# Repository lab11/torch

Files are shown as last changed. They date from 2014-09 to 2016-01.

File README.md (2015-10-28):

Torch
=====

<center>
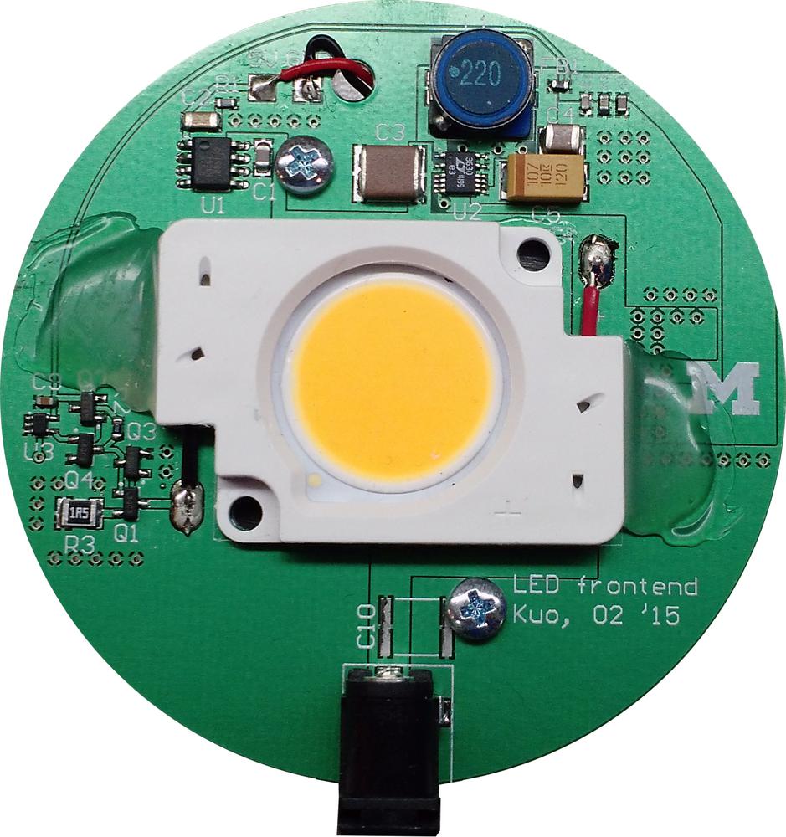
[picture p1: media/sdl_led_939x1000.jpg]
Torch

</center>

This system provides the hardware and software for a software-defined lighting platform.

Compile
-------

    git clone https://github.com/lab11/contiki
    cd contiki
    git co sdl

    cd ../torch/contiki/apps/coap
    make

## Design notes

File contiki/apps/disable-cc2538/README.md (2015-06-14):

Bare metal app that switches the antenna fully to the nRF51822.

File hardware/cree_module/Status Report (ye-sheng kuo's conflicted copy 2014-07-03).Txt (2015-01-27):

Output: NC Drill Files
Type  : NC Drill
From  : PCB Document [cree.PcbDoc]
   Generated File[cree.TXT]
   Generated File[cree.LDP]
   Generated File[cree.DRR]

Files Generated   : 3
Documents Printed : 0

Finished Output Generation At 11:31:57 AM On 5/7/2014

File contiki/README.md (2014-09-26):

Torch - Contiki
==============

This folder contains code to make Torch a
[Contiki](https://github.com/contiki-os/contiki) platform. Contiki has active
support of the CC2538 and this platform adds on drivers for the FRAM and
RTC chips.

Installation
------------

To compile apps for Torch you need this repository, the main Contiki repository,
and the toolchain.

1. Install the compilers. See
[this](https://github.com/contiki-os/contiki/tree/master/platform/cc2538dk#install-a-toolchain)
for a link to the best compiler to use for the CC2538

2. Clone the main contiki repository

        git clone https://github.com/contiki-os/contiki.git

3. Add the `/tools` directory in this folder to your path. This folder contains
a script for initializing the RTC with the current time. Something like:

        export PATH=$PATH:$HOME/git/torch/contiki/tools

4. Make sure the applications know where the main Contiki repository is.
Edit `apps/blink/Makefile` and make sure that `CONTIKI = ../../../../contiki`
actually points to where you cloned the Contiki repository.

Compiling an Application
------------------------

At this point compiling a Contiki application for torch 
should be very straightforward.

    cd apps/blink
    make

If you wanted to use a different platform (say the CC2538 evm with the SmartRF06
board):

    make TARGET=cc2538dk

Loading the Application to Torch
-------------------------------

Assuming you are using the serial bootloader (pins GND, VCC, !RESET,
BOOTLOADER_CTRL, BOOTLOADER_TX, and BOOTLOADER_RX) you can use the wonderful
[BSL script from JelmerT](https://github.com/JelmerT/cc2538-bsl) by:

    make install

Errors
------

It's possible these steps will not work. A major reason why is that the CC2538
platform in Contiki is changing rapidly and often adds in new features that
won't compile until the Torch platform is similarly updated. If this happens,
please raise an issue on this repository so that I can fix it.

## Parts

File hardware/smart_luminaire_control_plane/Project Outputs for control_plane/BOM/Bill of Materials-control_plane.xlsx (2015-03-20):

Designator | Value | Quantity | Footprint | Description | Supplier Part Number 1 | Comment
ANT1 |  | 1 | Chip Antenna | 2.4GHz Surface Mount Device (SMD) On Ground Antenna, 50 Ohms | FR05-S1-N-0102B
B1 |  | 1 | BAL-NRF01D3 | 50 ohm nominal input / conjugate match balun to nRF51822-CEAA | 497-13637-1-ND
B2 |  | 1 | 2450BM15A0002 | 2.45 GHz Balun for TI CC253X | 712-1536-1-ND
C1, C3, C5 | 4.7 uF | 3 | 0603 | Ceramic capacitor, 4.7u, 10V, 0603 package | 445-7482-1-ND
C2 | 1 uF | 1 | 0603 | Ceramic capacitor, 1 uF, 16 V, 0603 package | 445-1604-1-ND
C4 | 10000 pF | 1 | 0402 | Ceramic capacitor, 10000 pF, 16 V, 0402 package | 490-1313-1-ND
C6 | 10 uF | 1 | 0603 | Ceramic capacitor, 10 uF, 16 V, 0603 package | 445-9065-6-ND
C7, C9, C17, C25 | 1 uF | 4 | 0402 | Ceramic capacitor, 1 uF, 16V, 0402 package | 445-4978-1-ND
C8, C10, C11, C12, C13, C15, C16, C18, C19, C21, C23, C26, C27, C35, C46 | 0.1 uF | 15 | 0402 | Ceramic capacitor, 0.1u, 0402 package | 445-1265-1-ND
C14 | 220 pF | 1 | 0402 | Ceramic capacitor, 220 pF, 0402 package | 445-1254-1-ND
C20 | 0.047 uF | 1 | 0402 | Ceramic capacitor, 0.047u, 16V, 0402 package | 445-1264-1-ND
C22, C30, C36, C43 | 1000 pF | 4 | 0402 | Ceramic capacitor, 1000 pF, 0402 package | 445-6846-1-ND
C24 | 4.7 uF | 1 | 0603 - Polar Marking | Tantalum capacitor, 4.7 uF, 0603 package | 511-1496-1-ND
C28, C29 | 47 pF | 2 | 0402 | Ceramic capacitor, 47 pF, 0402 package | 709-1121-1-ND
C31, C32 | 22 pF | 2 | 0402 | Ceramic capacitor, 22 pF, 0402 package | 712-1274-1-ND
C33, C34 | 13 pF | 2 | 0402 | Ceramic capacitor, 13 pF, 50 V, 0402 package | 490-5925-1-ND
C37, C38, C40 | 100 pF | 3 | 0402 | Ceramic capacitor, 100 pF, 0402 package | 399-11246-1-ND
C39 | 2200 pF | 1 | 0402 | Ceramic capacitor, 2200 pF, 0402 package | 445-1257-1-ND
C41, C42, C44, C45 | 12 pF | 4 | 0402 | Ceramic capacitor, 12 pF, 0402 package | 712-1256-1-ND
D1, D4 |  | 2 | 0402 - DIODE | LED, Green, 0402 | 511-1592-1-ND
D2 |  | 1 | 0402 - DIODE | LED, Orange, 0402 | 511-1590-1-ND
D3 |  | 1 | 0402 - DIODE | LED, Red, 0402 | 511-1593-1-ND
FB1 |  | 1 | 0402 | Ferrite Bead, 150 mA, 0402 package | 587-1835-1-ND
J1 |  | 1 | Micro USB-B | CONN USB MICRO B RECPT SMT R/A | 609-4616-6-ND
P1, P3 |  | 2 | SSM-104-F-DV | Samtec 2x4 100 mil female connector | SSM-104-F-DV | Samtec
P2, P4 |  | 2 | SAM_CLP_2_4 | Samtec CLP 2x4 0.05" Female Header | CLP-104-02-G-D | Samtec
P6 |  | 1 | CAS-220A | DPDT dip switch | CAS220JCT-ND
R1, R12 | 205 | 2 | 0402 | Chip resistor, 205, 0402 package | 541-205LCT-ND
R2, R3, R4 | 0 | 3 | 0402 | Chip resistor, 0, 0402 package | 541-0.0YBCT-ND
R15, R24 | 0 | 2 | 0402 | Chip resistor, 0, 0402 package | 541-0.0YBCT-ND | DNI
R5, R6 | 33 | 2 | 0402 | Chip resistor, 33, 0402 package | 541-33.0LCT-ND | DNI
R7, R25, R26 | 100K | 3 | 0402 | Chip resistor, 100K, 0402 package | 541-100KLCT-ND | DNI
R8 | 2.2K | 1 | 0402 | Chip resistor, 2.2K, 0402 package | 541-2.20KLCT-ND
R9 | 56K | 1 | 0402 | Chip resistor, 56K, 0402 package | P56KDECT-ND
R10 | 270 | 1 | 0402 | Chip resistor, 270, 0402 package | 541-270LCT-ND
R11 | 374 | 1 | 0402 | Chip resistor, 374, 0402 package | 541-374LCT-ND
R13, R14, R16, R17, R18, R19, R20, R21, R22, R23 | 100 | 10 | 0402 | Chip resistor, 100, 0402 package | 541-100LCT-ND
R27 | 10K | 1 | 0402 | Chip resistor, 10K, 0402 package | 541-10.0KLDKR-ND
U1 |  | 1 | DFN-10 | Dual 2.6A, 2.5V to 5.5V, Ideal Diodes in 3mm × 3mm DFN | LTC4413EDD#TRPBFCT-ND
U2 |  | 1 | SON-6 | 500mA, Low Quiescent Current, Ultra-Low Noise, High PSRR Low-Dropout Linear Regulator | 296-24289-1-ND
U3 |  | 1 | QFN56 | A Powerful System-On-Chip for 2.4-GHz IEEE 802.15.4, 6LoWPAN and ZigBee Applications | 296-35797-1-ND
U4 |  | 1 | QFN-48 | Multiprotocol Bluetooth® low energy/2.4 GHz RF System on Chip | 1490-1032-1-ND
U5 |  | 1 | QFN-32 | FT232R USB UART | 768-1008-1-ND
U6 |  | 1 | WSON | 64 Mbit SPI Serial Dual I/O Flash | SST25VF064C-80-4I-Q2AE-CT-ND
U7 |  | 1 | minimold-6 | GaAs Integrated Circuit for L, S-Band SPDT Switch | UPG2214TB-E4-ACT-ND
U8 |  | 1 | SC-70-5 (DCK) | LOW POWER, 1.8/2.5/3.3-V INPUT, 3.3-V CMOS OUTPUT, SINGLE SCHMITT-TRIGGER INVERTER GATE | 296-27392-1-ND
Y1 |  | 1 | ABS05 | 32768 Hz SMD Low profile crystal | 535-11899-1-ND
Y2 |  | 1 | ECX-31B | SMD TUNING FORK CRYSTAL | XC1950CT-ND
Y3 |  | 1 | CX2520 | Crystal oscillator | 1253-1121-1-ND
Y4 |  | 1 | FA-128 | MHz Range Crystal Unit | SER3800CT-ND
Y5 |  | 1 | RV-3049-C3 | Real Time Clock Module with SPI-Bus

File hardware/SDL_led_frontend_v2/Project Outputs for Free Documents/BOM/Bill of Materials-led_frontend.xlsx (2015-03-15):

Designator | Value | Quantity | Footprint | Description | Supplier Part Number 1
C1 | 1 uF | 1 | 0805 | Ceramic capacitor, 1 uF, 100 V, 0805 package | 445-5205-1-ND
C2 | 22 uF | 1 | 1206 | Ceramic capacitor, 22 uF, 1206 package | 1276-2728-1-ND
C3, C10 | 4.7 uF | 2 | 2220 | Ceramic capacitor, 4.7u, 2220 package | 445-1450-1-ND
C4 | 100 uF | 1 | 1210 | Ceramic capacitor, 100u, 1210 package | 1276-3364-1-ND
C5 | 100 uF | 1 | 2917 | Tantalum capacitor, 100u, 2917 package | 399-3769-1-ND
C6, C9 | 0.1 uF | 2 | 0603 | Ceramic capacitor, 0.1 uF, 0603 package | 445-1316-1-ND
C7 | 1 uF | 1 | 0603 | Ceramic capacitor, 1 uF, 16 V, 0603 package | 445-1604-1-ND
C8 | 10 uF | 1 | 0603 | Ceramic capacitor, 10 uF, 16 V, 0603 package | 445-9065-6-ND
FB1 |  | 1 | 0603 | Ferrite Bead, 500 mA, 0603 package | 490-1011-1-ND
J1 |  | 1 | molex | LED Array Holders for CREE* XLamp† Arrays | WM10352-ND
J2 |  | 1 | PJ-102AH | CONN PWR JACK 2.1X5.5MM HIGH CUR | CP-102AH-ND
L1 | 22 uH | 1 | SLF10145 | Inductor, 22 uH, TDK SLF10145 | 445-1981-1-ND
P1, P2 |  | 2 | HW-04-20-F-D-900-SM | Samtec 2x4 100 mil connector
P3 |  | 1 | 2x2 header SMD | 2x2 100 mil header SMD | 609-4463-6-ND
Q1, Q3, Q4 |  | 3 | SOT23-3 | N-Channel 60-V (D-S) MOSFET | SI2308BDS-T1-E3CT-ND
Q2 |  | 1 | SOT23-3 | P-Channel 60-V (D-S) MOSFET | SI2309CDS-T1-E3CT-ND
R1 | 1 | 1 | 0603 | Chip resistor, 1, 0603 package | 541-1.00HHCT-ND
R2 | 47 | 1 | 0603 | Chip resistor, 47, 0603 package | 541-47.0HCT-ND
R3 | 1.5 | 1 | 1210 | Chip resistor, 1.5, 1210 package | P1.5VTR-ND
U1 |  | 1 | SOIC-8 | Ultra-Low Quiescent Current LDO Voltage Regulator | LM2936HVMAX-5.0/NOPBCT-ND
U2 |  | 1 | MSE16(12) | High Efficiency, 65V 500mA synchronous Step-Down Converter | LTC3630EMSE#PBF-ND
U3 |  | 1 | SC-70-5 (DCK) | LOW POWER, 1.8/2.5/3.3-V INPUT, 3.3-V CMOS OUTPUT, SINGLE SCHMITT-TRIGGER INVERTER GATE | 296-27392-1-ND

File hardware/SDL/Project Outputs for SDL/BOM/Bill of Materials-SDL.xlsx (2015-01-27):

Designator | Value | Quantity | Footprint | Description | Supplier 1 | Supplier Part Number 1 | Comments
ANT1 |  | 1 | Chip Antenna | 2.4GHz Surface Mount Device (SMD) On Ground Antenna, 50 Ohms | RichardsonRFPD | FR05-S1-N-0102B
B1 |  | 1 | 2450BM14A0002 | 2.45 GHz Balun for nRF8001 | Digi-Key | 712-1574-1-ND
B2 |  | 1 | 2450BM15A0002 | 2.45 GHz Balun for TI CC253X | Digi-Key | 712-1536-1-ND
C1, C3, C5, C6, C8, C9, C10, C16, C19, C22, C23, C30, C34, C46, C47 | 0.1 uF | 15 | 0402 | Ceramic capacitor, 0.1u, 0402 package | Digi-Key | 445-1265-1-ND
C2, C4, C11, C17, C21, C33 | 1 uF | 6 | 0402 | Ceramic capacitor, 1 uF, 0402 package | Digi-Key | 445-5000-1-ND
C7 | 220 pF | 1 | 0402 | Ceramic capacitor, 220 pF, 0402 package | Digi-Key | 445-1254-1-ND
C12, C28, C39, C43 | 1000 pF | 4 | 0402 | Ceramic capacitor, 1000 pF, 0402 package | Digi-Key | 445-6846-1-ND
C36 | 1000 pF | 1 | 0402 | Ceramic capacitor, 1000 pF, 0402 package | Digi-Key | 445-6846-1-ND | No load
C13 | 4.7 uF | 1 | 2220 | Ceramic capacitor, 4.7u, 2220 package | Digi-Key | 445-1450-1-ND
C14 | 100 uF | 1 | 1210 | Ceramic capacitor, 100u, 1210 package | Digi-Key | 1276-3364-1-ND
C15 | 100 uF | 1 | 2917 | Tantalum capacitor, 100u, 2917 package | Digi-Key | 399-3769-1-ND
C18, C32 | 10 uF | 2 | 0603 | Ceramic capacitor, 10 uF, 0603 package | Digi-Key | 445-4112-1-ND
C20 | 4.7 uF | 1 | 0603 - Polar Marking | Tantalum capacitor, 4.7 uF, 0603 package | Digi-Key | 511-1496-1-ND
C24, C25 | 47 pF | 2 | 0402 | Ceramic capacitor, 47 pF, 0402 package | Digi-Key | 709-1121-1-ND
C26, C27 | 22 pF | 2 | 0402 | Ceramic capacitor, 22 pF, 0402 package | Digi-Key | 712-1274-1-ND
C29 | 1 uF | 1 | 0603 | Ceramic capacitor, 1 uF, 0603 package | Digi-Key | 445-1321-1-ND
C31 | 0.033 uF | 1 | 0402 | Ceramic capacitor, 0.033 uF, 0402 package | Digi-Key | 445-7334-1-ND
C35 | 2200 pF | 1 | 0402 | Ceramic capacitor, 2200 pF, 0402 package | Digi-Key | 445-1257-1-ND
C37, C38, C44, C45 | 12 pF | 4 | 0402 | Ceramic capacitor, 12 pF, 0402 package | Digi-Key | 712-1256-1-ND
C40, C41, C42 | 100 pF | 3 | 0402 | Ceramic capacitor, 100 pF, 0402 package | Digi-Key | 399-11246-1-ND
D1, D3 |  | 2 | 0402 - DIODE | LED, Green, 0402 | Digi-Key | 511-1592-1-ND
D2 |  | 1 | 0402 - DIODE | LED, Red, 0402 | Digi-Key | 511-1593-1-ND
FB1, FB2 |  | 2 | 0402 | Ferrite Bead, 150 mA, 0402 package | Digi-Key | 587-1835-1-ND
J1 |  | 1 | Micro USB-B | CONN USB MICRO B RECPT SMT R/A | Digi-Key | 609-4616-6-ND
J2, J3, J4, J5 |  | 4 | SFM-105-02-L-S | Samtec connector, 1.27 mm, single row, 5 pos SMD | Samtec
L1 | 22 uH | 1 | SLF10145 | Inductor, 22 uH, TDK SLF10145 | Digi-Key | 445-1981-1-ND
L2 | 15 nH | 1 | 0402 | Chip inductor, 15 nH, 0402 package | Digi-Key | 712-1408-1-ND
L3 | 10 uH | 1 | 0603 | Chip inductor, 10 uH, 0603 package | Digi-Key | 445-3608-1-ND
P1 |  | 1 | 1x3 header | 100 mils standard header | Digi-Key | 3M9448-ND
P2 |  | 1 | 2x2 header SMD | 2x2 100 mil header SMD | Digi-Key | 609-4463-6-ND
R1, R21, R23, R24 | 100K | 4 | 0402 | Chip resistor, 100K, 0402 package | Digi-Key | 541-100KLCT-ND | No load
R2 | 2.2K | 1 | 0402 | Chip resistor, 2.2K, 0402 package | Digi-Key | 541-2.20KLCT-ND
R20 | 2.2K | 1 | 0402 | Chip resistor, 2.2K, 0402 package | Digi-Key | 541-2.20KLCT-ND | No load
R3 | 56K | 1 | 0402 | Chip resistor, 56K, 0402 package | Digi-Key | P56KDECT-ND
R10 | 750 | 1 | 0402 | Chip resistor, 750, 0402 package | Digi-Key | 541-750LCT-ND
R4, R11 | 619 | 2 | 0402 | Chip resistor, 750, 0402 package | Digi-Key | 541-619LCT-ND
R5, R6, R7, R14 | 0 | 3 | 0402 | Chip resistor, 0, 0402 package | Digi-Key | 541-0.0YBCT-ND
R14 | 0 | 1 | 0402 | Chip resistor, 0, 0402 package | Digi-Key | 541-0.0YBCT-ND | No load
R8, R9 | 33 | 2 | 0402 | Chip resistor, 33, 0402 package | Digi-Key | 541-33.0LCT-ND | No load
R12, R13, R15, R16, R17, R18, R19 | 10K | 7 | 0402 | Chip resistor, 10K, 0402 package | Digi-Key | 541-10.0KLDKR-ND
R22 | 22K | 1 | 0402 | Chip resistor, 22K, 0402 package | Digi-Key | 541-22.0KLCT-ND
SW1 |  | 1 | CHS-06TA | SLIDE SWITCHES | Digi-Key | 563-1009-1-ND
U1 |  | 1 | QFN56 | A Powerful System-On-Chip for 2.4-GHz IEEE 802.15.4, 6LoWPAN and ZigBee Applications | Digi-Key | 296-35797-1-ND
U2 |  | 1 | MSE16(12) | High Efficiency, 65V 500mA synchronous Step-Down Converter | Digi-Key | LTC3630EMSE#PBF-ND
U3 |  | 1 | QFN-32 | FT232R USB UART | Digi-Key | 768-1008-1-ND
U4 |  | 1 | QFN32 | Single-chip Bluetooth low energy solution | Digi-Key | 1490-1026-ND
U5 |  | 1 | SC-70-5 (DCK) | LOW POWER, 1.8/2.5/3.3-V INPUT, 3.3-V CMOS OUTPUT, SINGLE SCHMITT-TRIGGER INVERTER GATE | Digi-Key | 296-27392-1-ND
U6 |  | 1 | WSON | 64 Mbit SPI Serial Dual I/O Flash | Digi-Key | SST25VF064C-80-4I-Q2AE-CT-ND
U7 |  | 1 | minimold-6 | GaAs Integrated Circuit for L, S-Band SPDT Switch | Digi-Key | UPG2214TB-E4-ACT-ND
Y1 |  | 1 | ABS05 | 32768 Hz SMD Low profile crystal | Digi-Key | 535-11899-1-ND
Y2 |  | 1 | TSX-3225 | MHz Range Crystal Unit | Digi-Key | SER3628CT-ND
Y3 |  | 1 | FA-128 | MHz Range Crystal Unit | Digi-Key | SER3800CT-ND | Non Stock
Y4 |  | 1 | RV4162 | Real Time Clock Module with I2C Bus | Newark | 09X0517

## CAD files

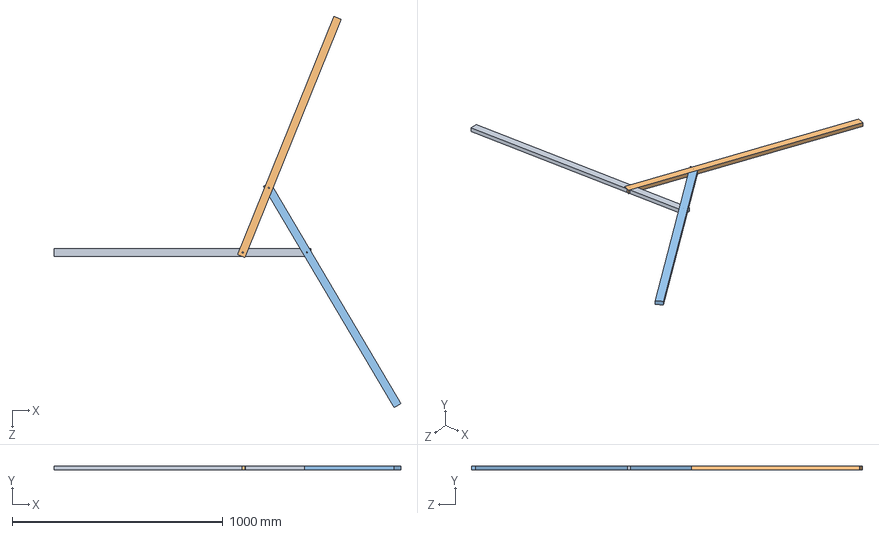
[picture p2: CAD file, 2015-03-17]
chandelier/frame.SLDASM
1646.4 x 19.1 x 1856.4 mm
frame_12
frame_13
frame_14

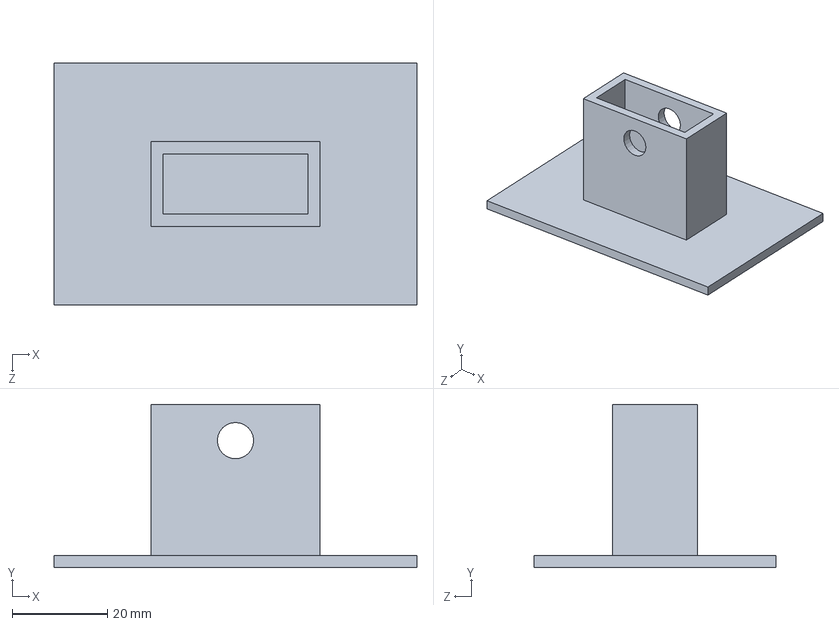
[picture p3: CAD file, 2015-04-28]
chandelier/wall_mount.SLDPRT
76.2 x 34.3 x 50.8 mm

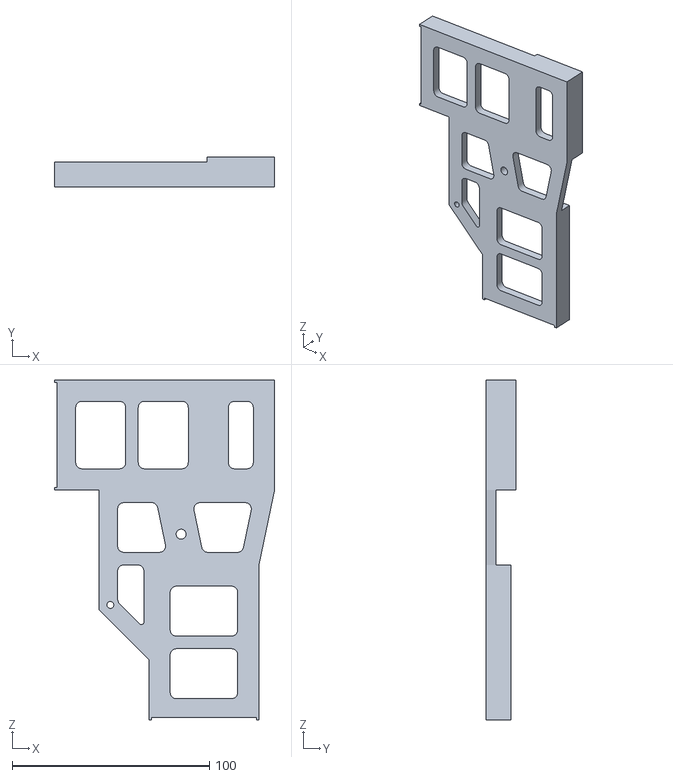
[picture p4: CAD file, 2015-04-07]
hardware/calibration/Laser_Holder.stl
111.8 x 15.2 x 172.6

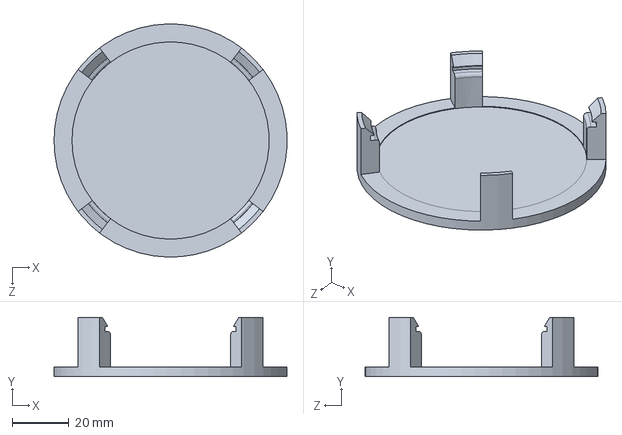
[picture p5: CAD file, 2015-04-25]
mount/torch-holder.SLDPRT
82.2 x 20.9 x 82.3 mm

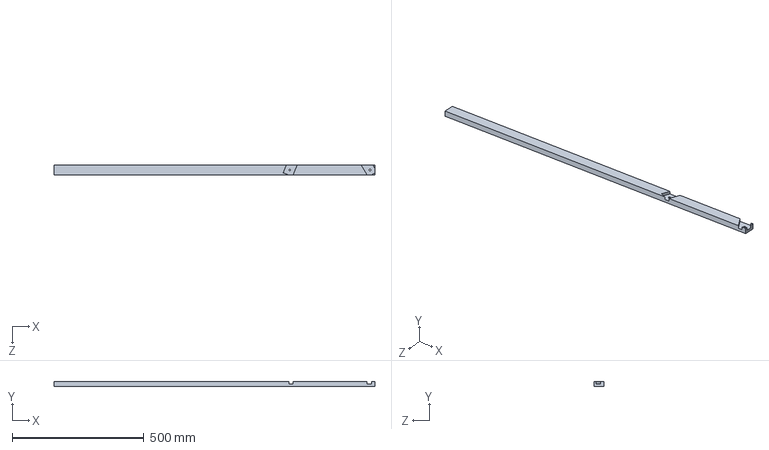
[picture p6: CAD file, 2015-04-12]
chandelier/frame_12.SLDPRT
1219.2 x 19.1 x 38.1 mm

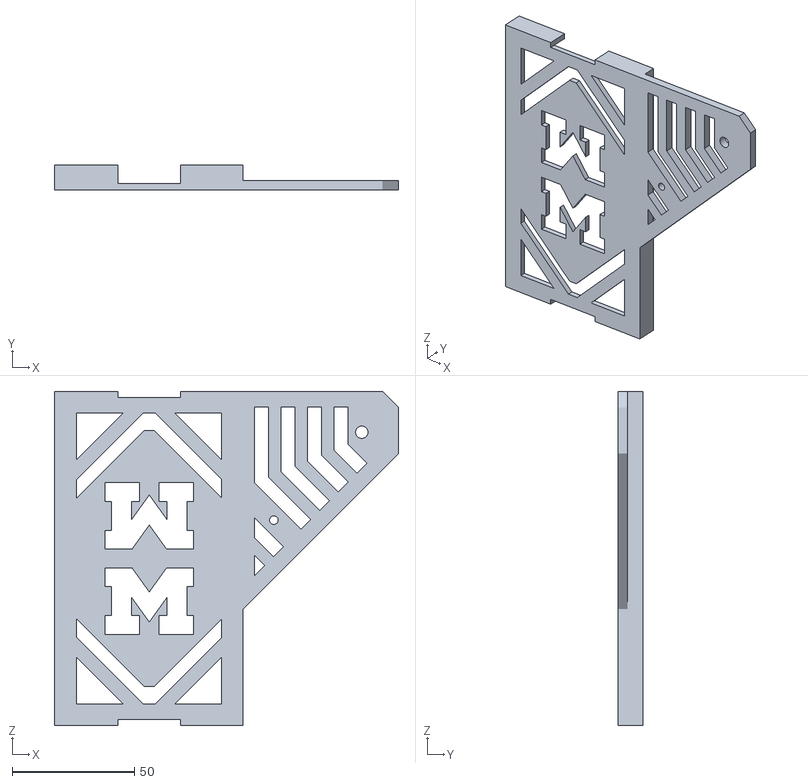
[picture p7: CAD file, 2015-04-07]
hardware/calibration/Phone_Holder.stl
140.6 x 10.2 x 136.5

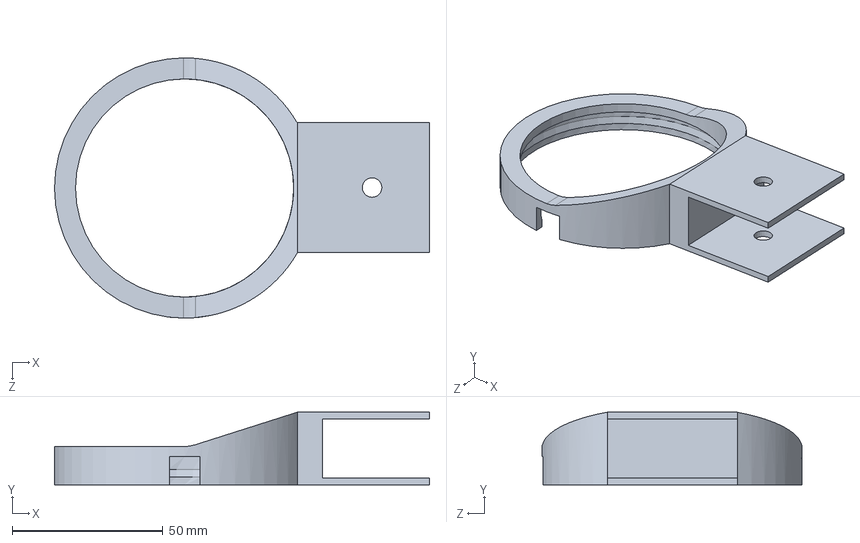
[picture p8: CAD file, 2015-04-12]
chandelier/globe_mount_bulb4.SLDPRT
124.5 x 24.1 x 86.4 mm

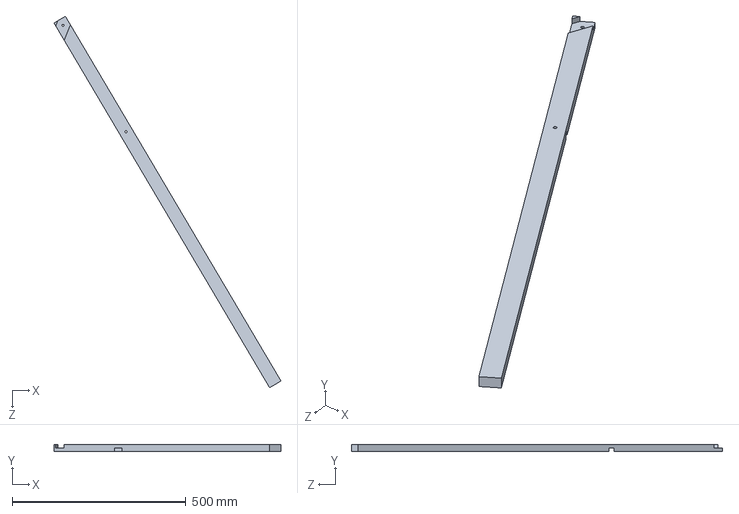
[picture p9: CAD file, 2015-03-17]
chandelier/frame_14.SLDPRT
653.3 x 19.1 x 1068.9 mm

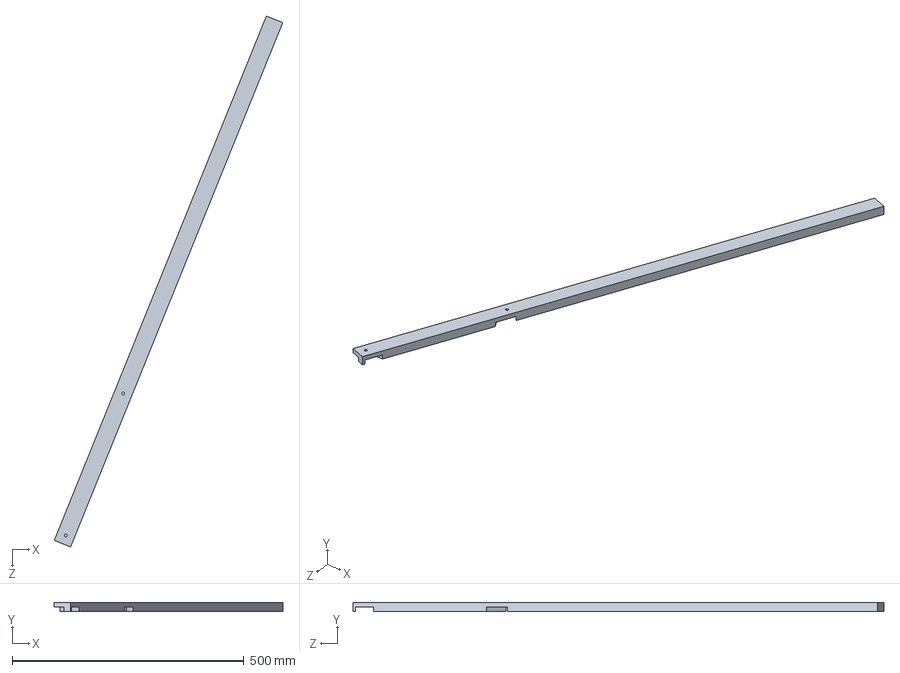
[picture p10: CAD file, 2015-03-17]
chandelier/frame_13.SLDPRT
492.5 x 19.1 x 1144.5 mm

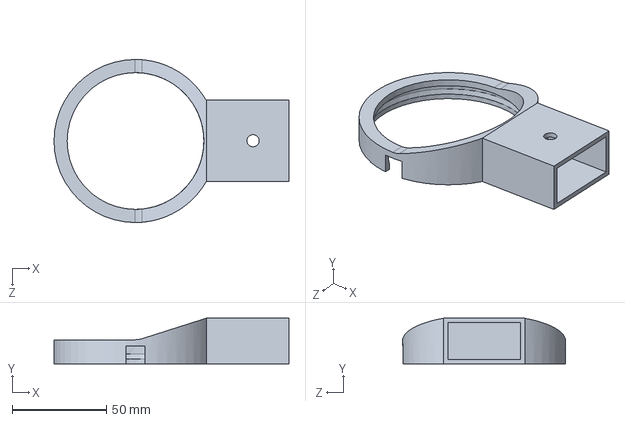
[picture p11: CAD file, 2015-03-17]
chandelier/globe_mount.SLDPRT
124.5 x 24.1 x 86.4 mm

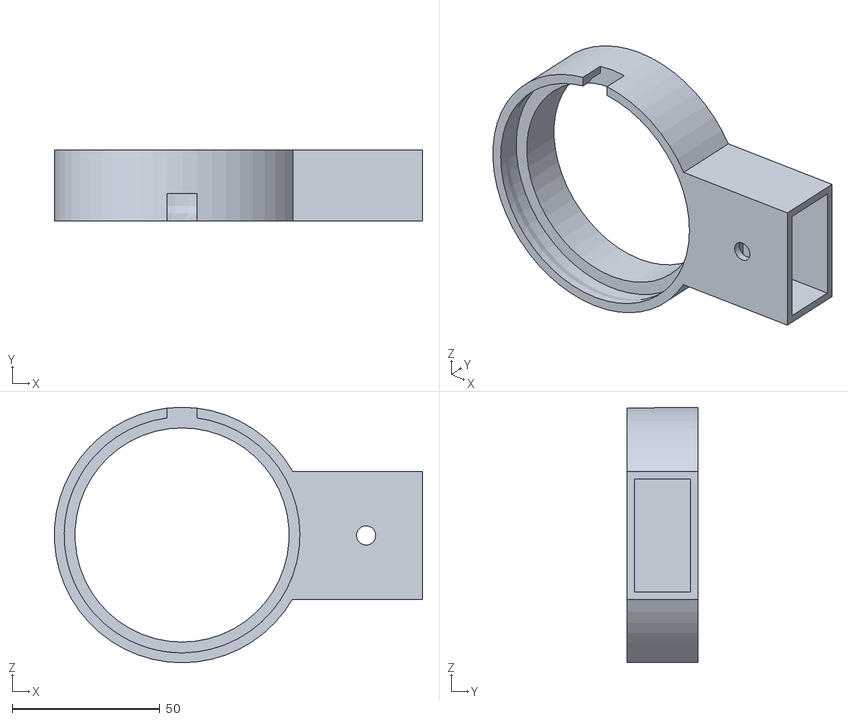
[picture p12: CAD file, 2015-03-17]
chandelier/globe_mount2.STL
124.4 x 24.1 x 86.4

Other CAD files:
chandelier/globe_mount3.STL
chandelier/frame.SLDPRT
chandelier/globe_mount.STL
chandelier/globe_mount_bulb4.STL
chandelier/wall_mount.STL
hardware/calibration/Laser_Holder.ipt
hardware/calibration/OptiTrack_Calibrator.ipt
hardware/calibration/Phone_Holder.ipt
mount/torch-holder.STL

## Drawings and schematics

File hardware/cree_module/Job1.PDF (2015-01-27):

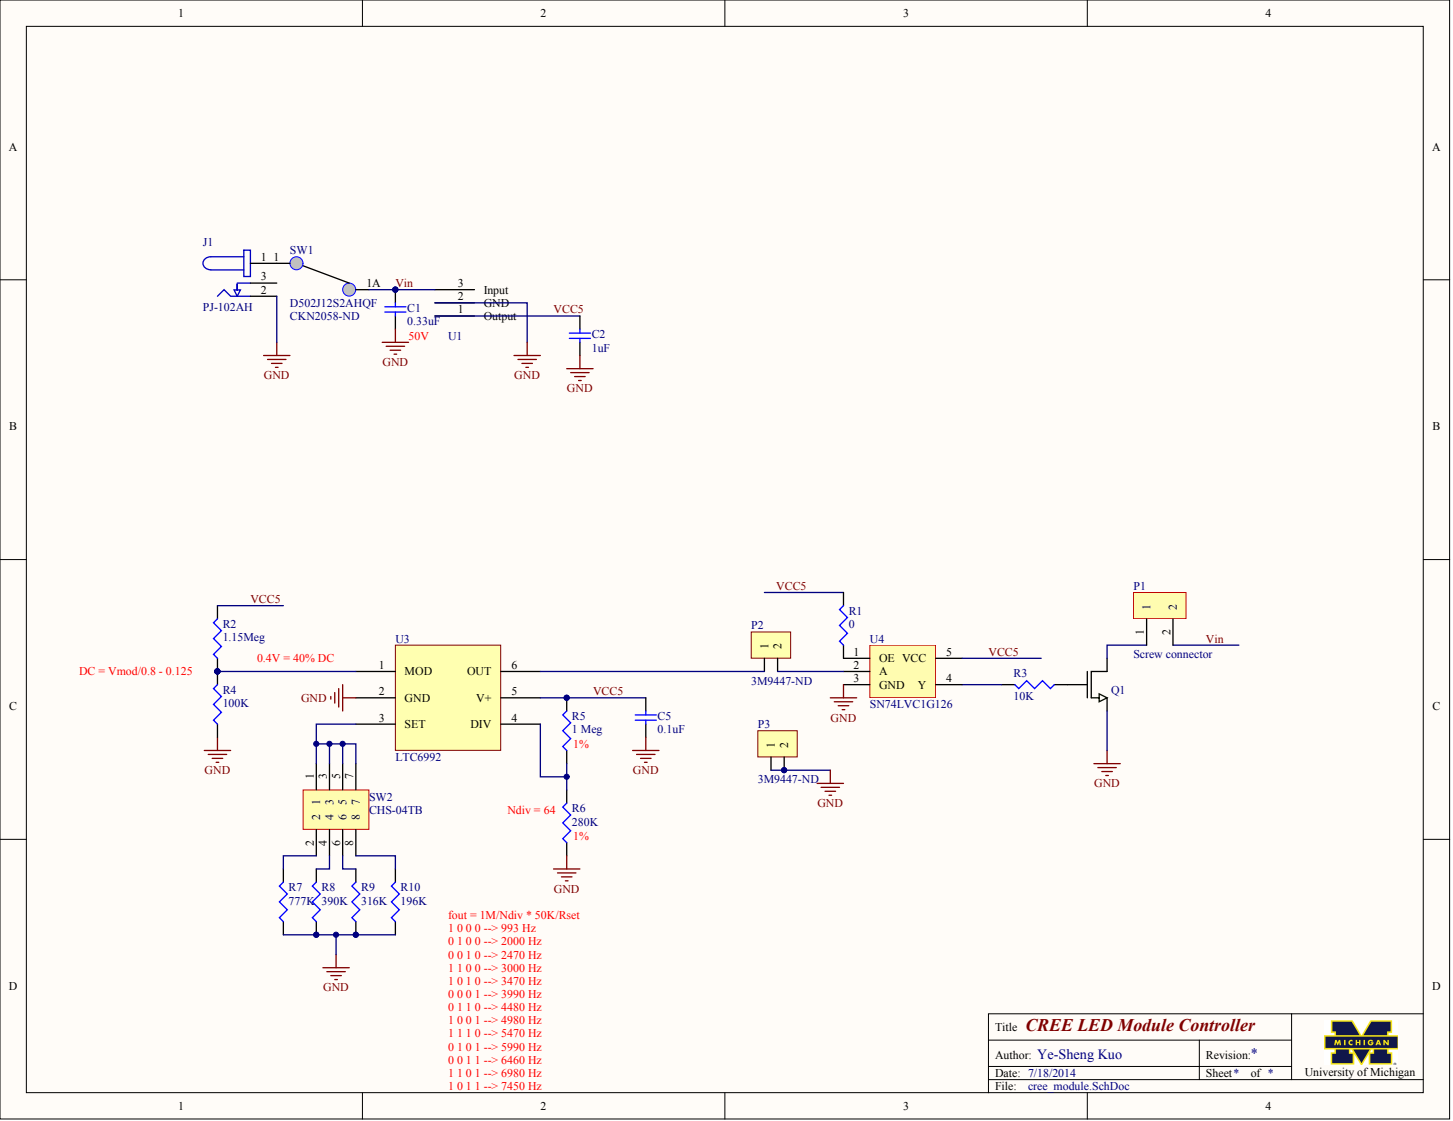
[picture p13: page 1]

CREE LED Module Controller Title | University of Michigan

Author: Ye-Sheng Kuo | Revision: *
Date: 7/18/2014 | Sheet * of *

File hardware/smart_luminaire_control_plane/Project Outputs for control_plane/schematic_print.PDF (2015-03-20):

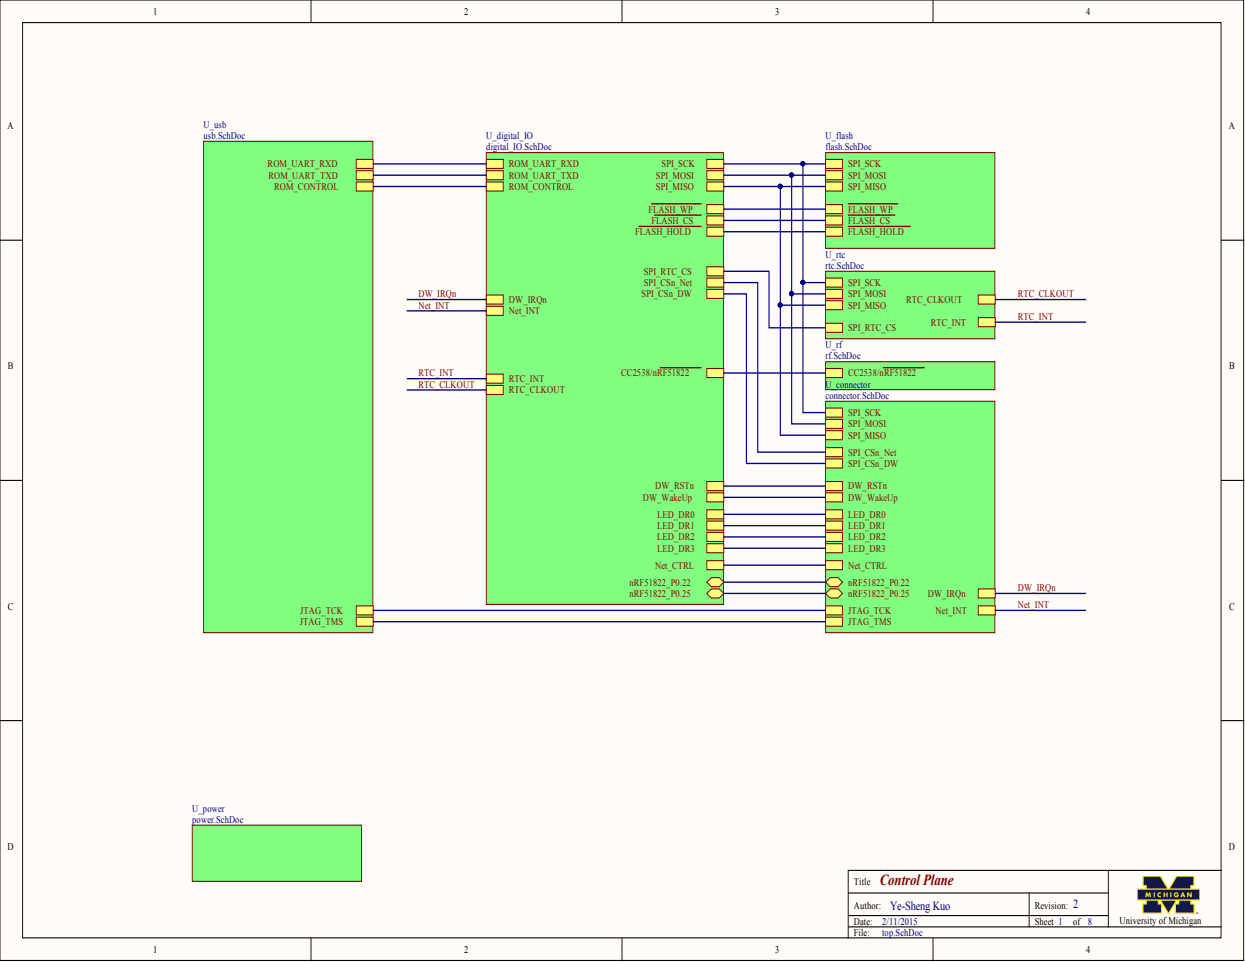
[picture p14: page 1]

aontrol Plane Title | University of Michigan

Author: Ye-Sheng Kuo | Revision:
Date: | Sheet of

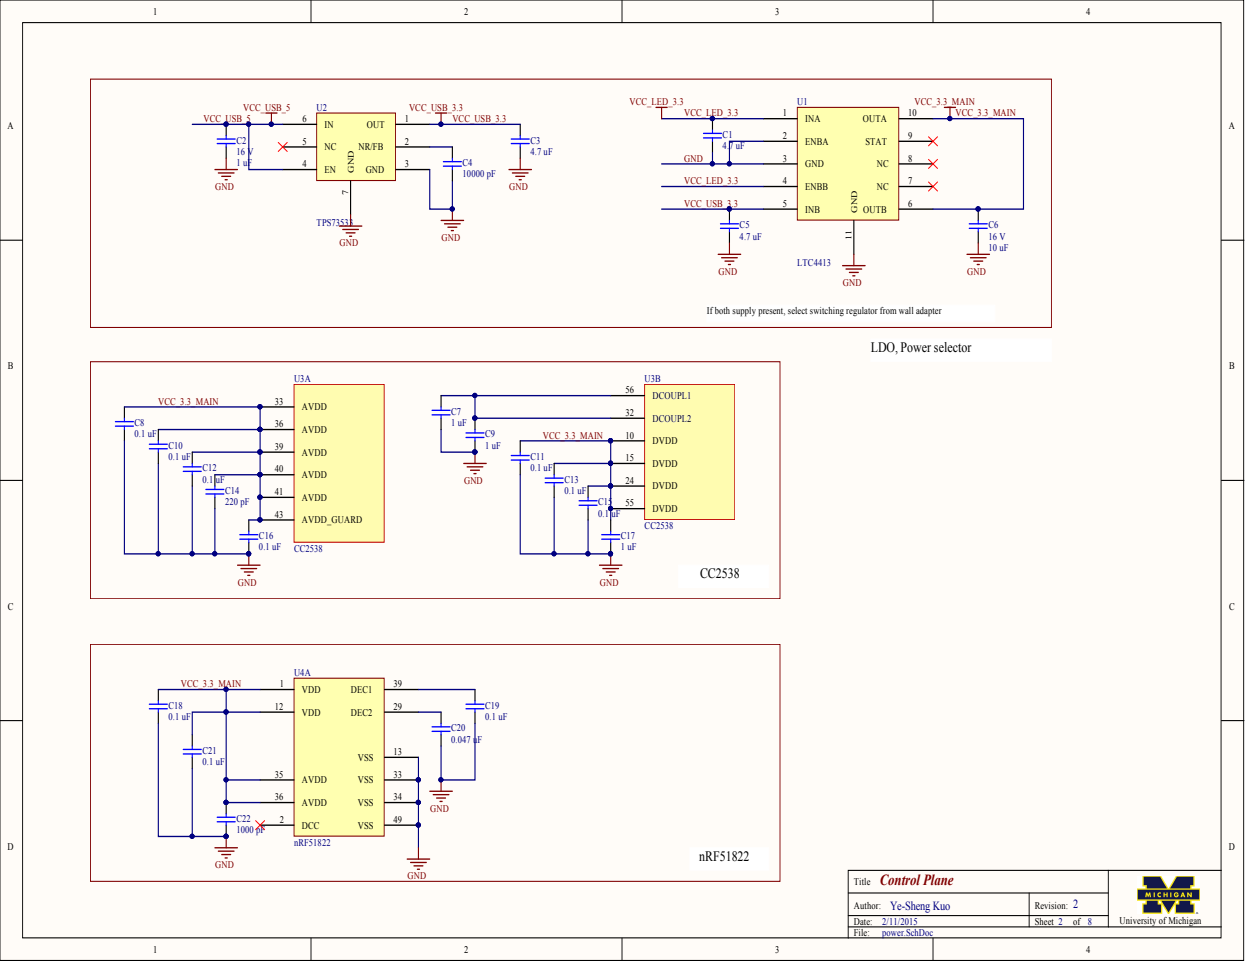
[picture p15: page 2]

If both supply present, select switching regulator from wall adapter

DVDD 15

DVDD 24

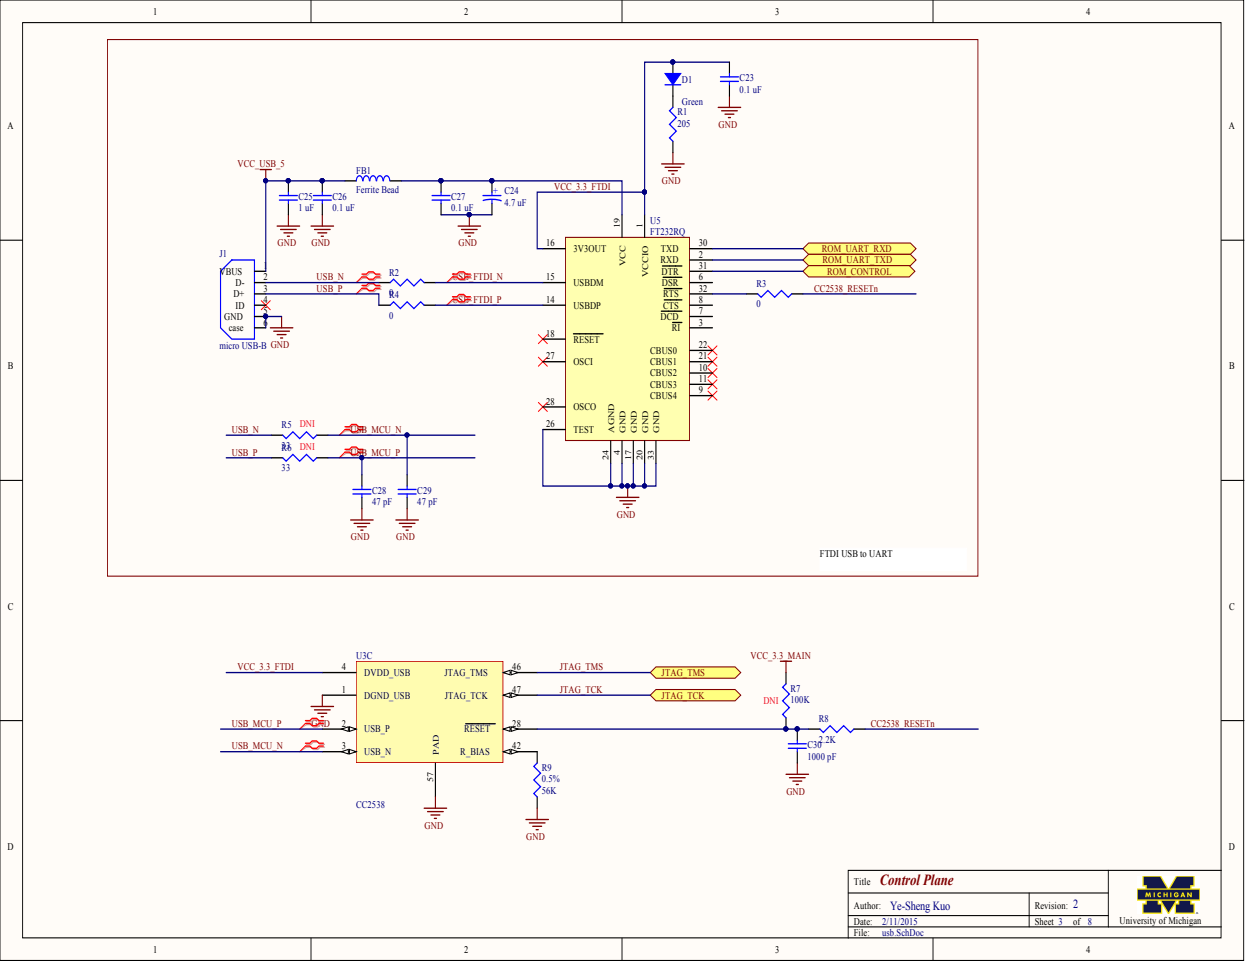
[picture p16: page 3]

FTDI USB to UART

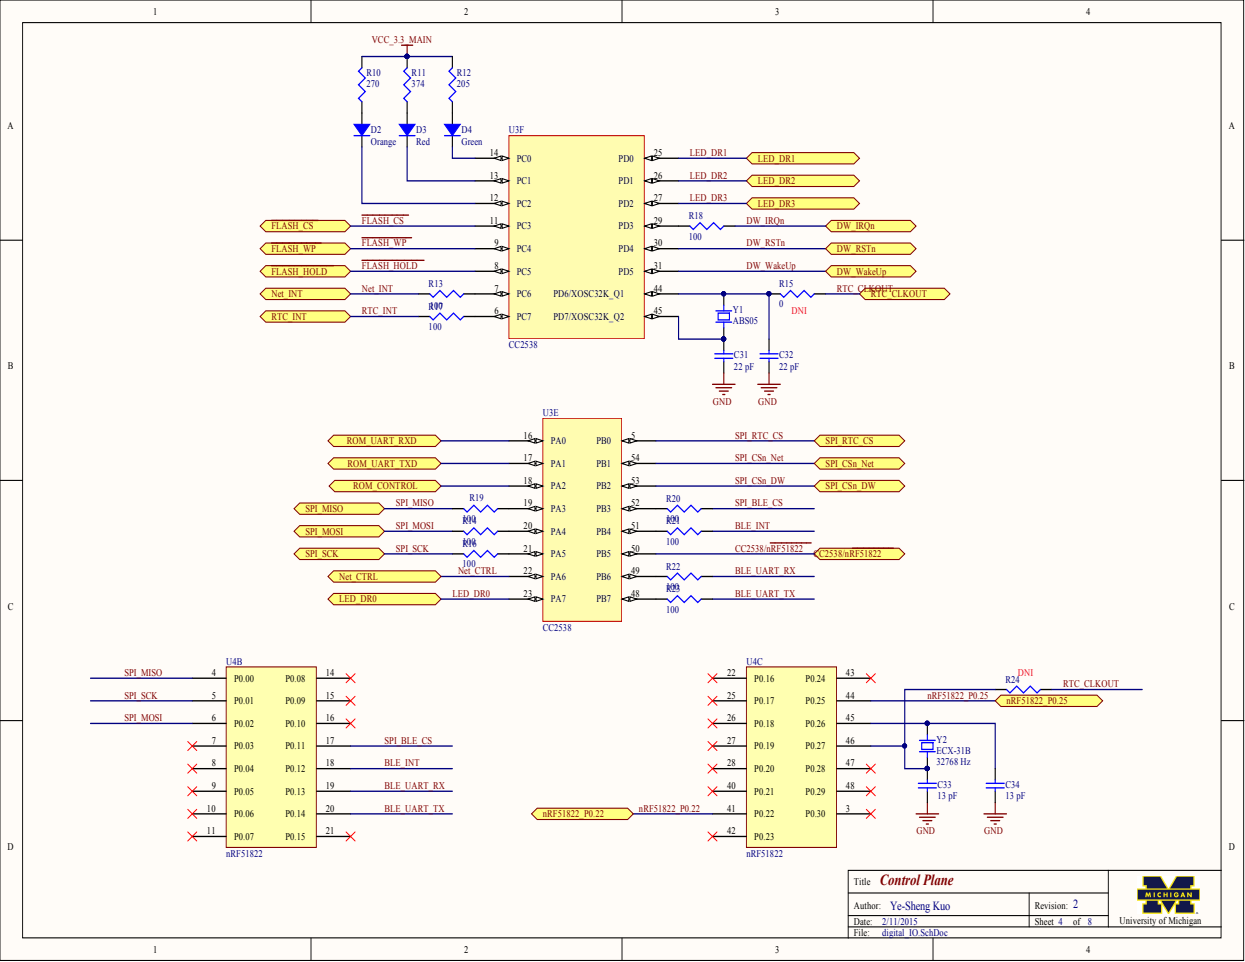
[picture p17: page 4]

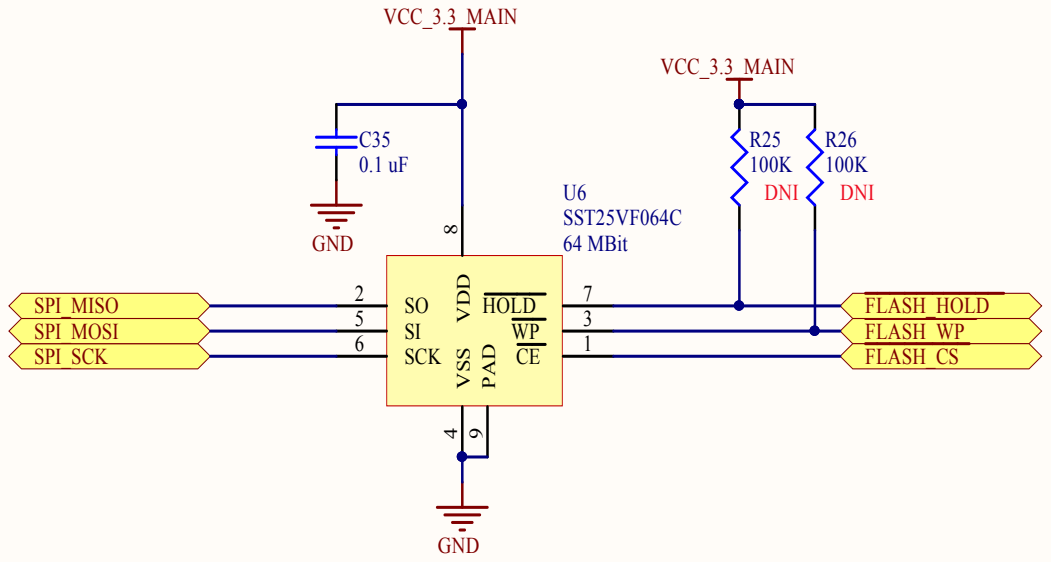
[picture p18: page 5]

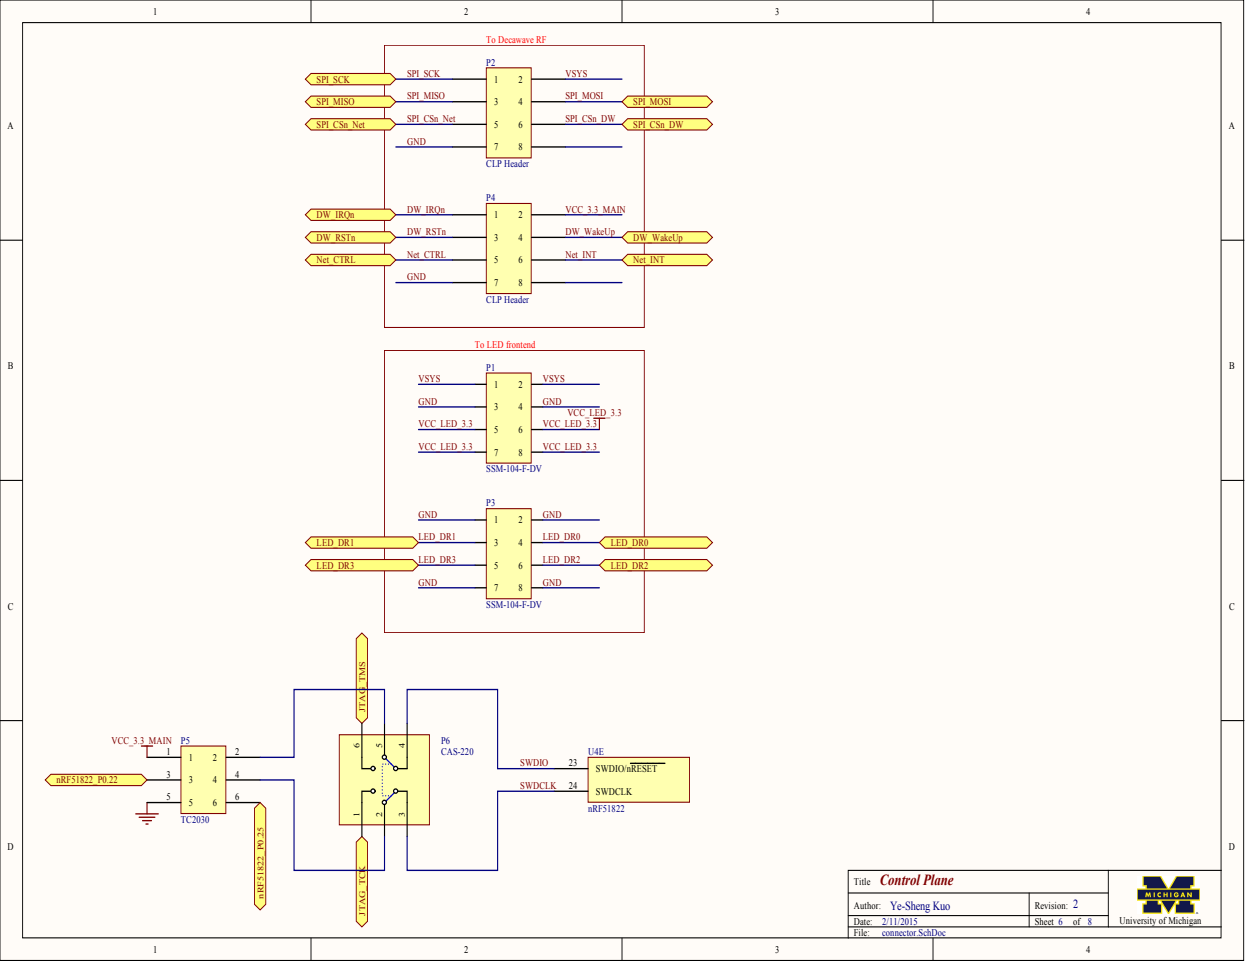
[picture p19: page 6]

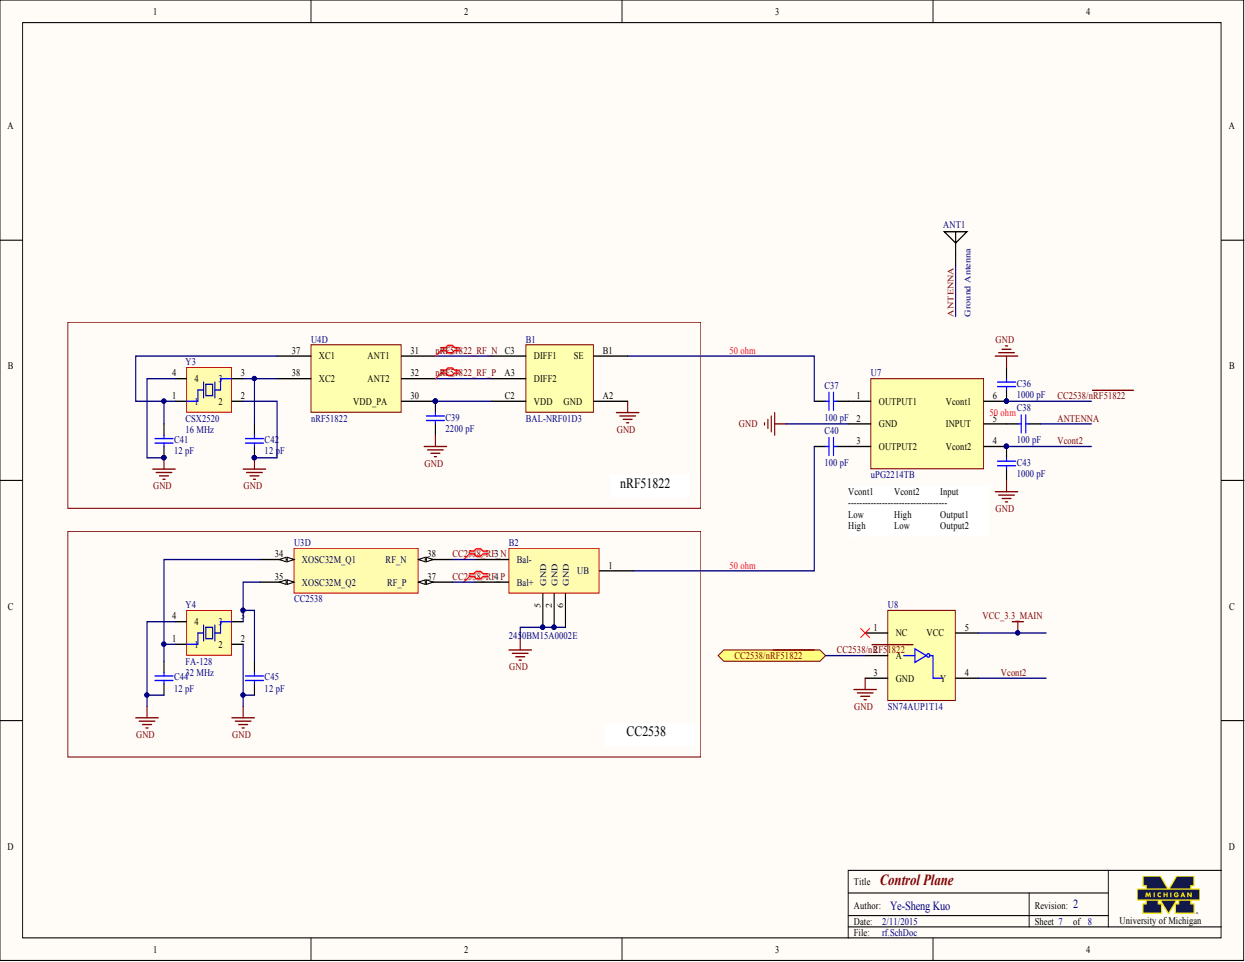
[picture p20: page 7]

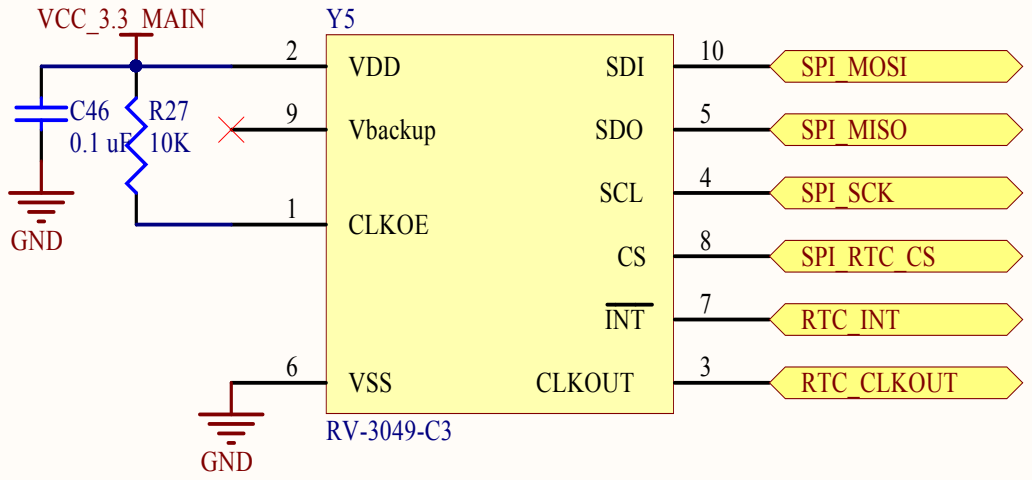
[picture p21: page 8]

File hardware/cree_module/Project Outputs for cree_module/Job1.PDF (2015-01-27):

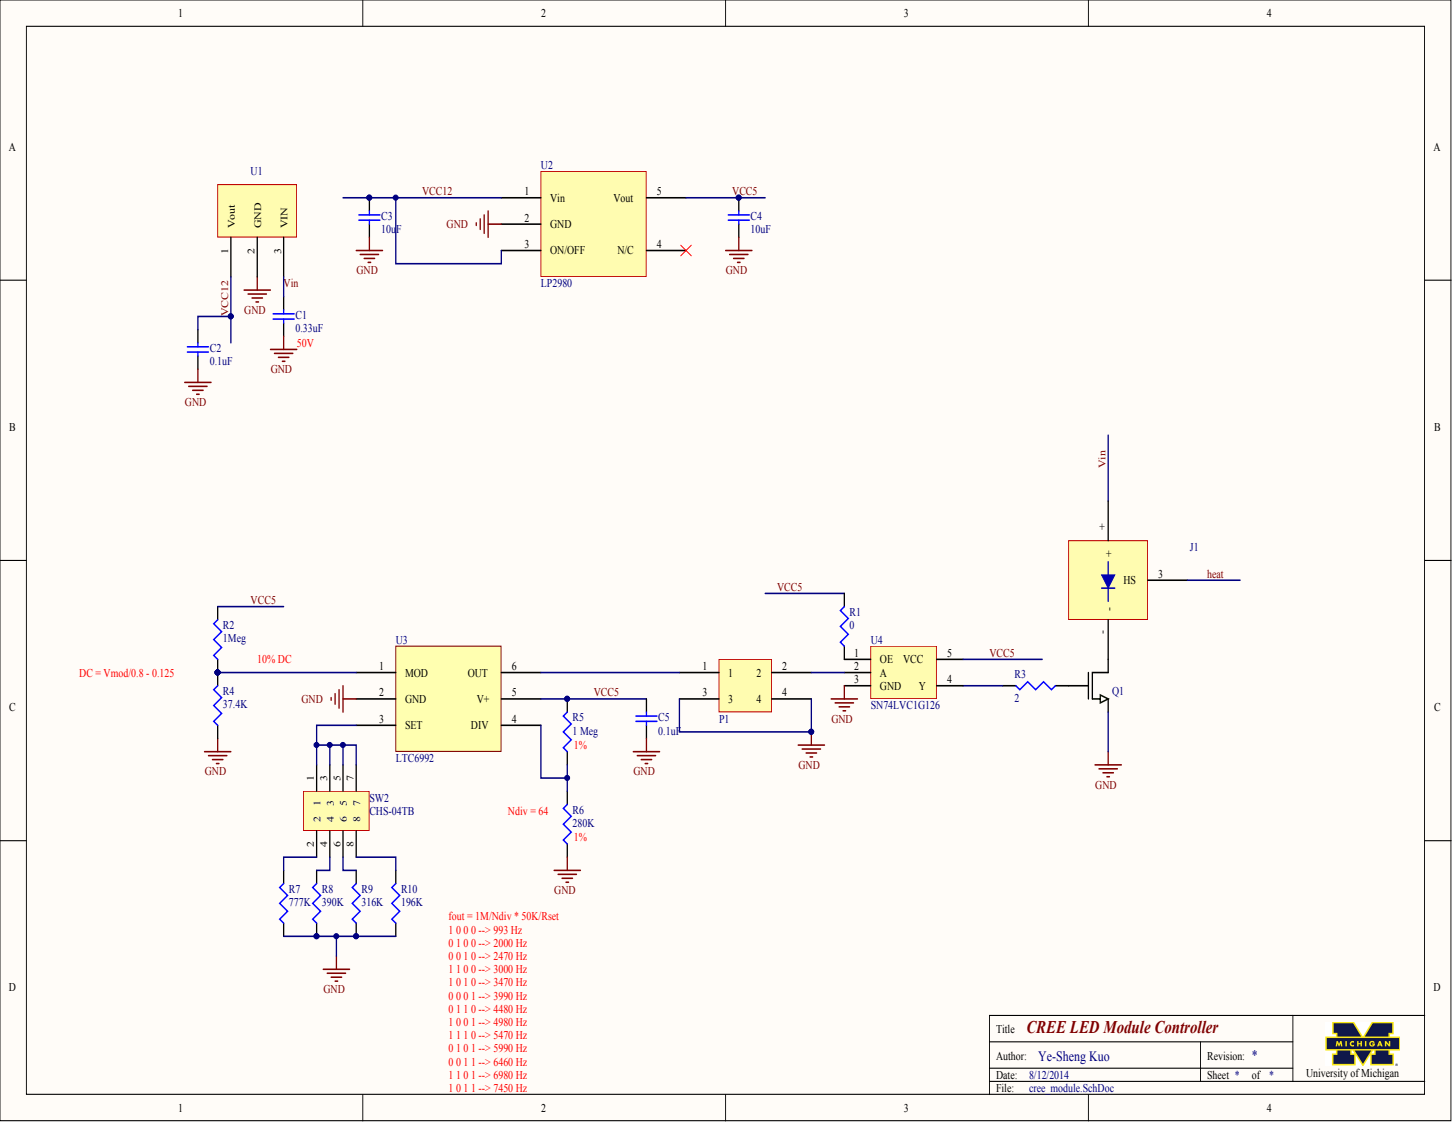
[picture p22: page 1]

Title CREE LED Module Controller | University of Michigan

Author: Ye-Sheng Kuo | Revision: *
Date: 8/12/2014 | Sheet * of *

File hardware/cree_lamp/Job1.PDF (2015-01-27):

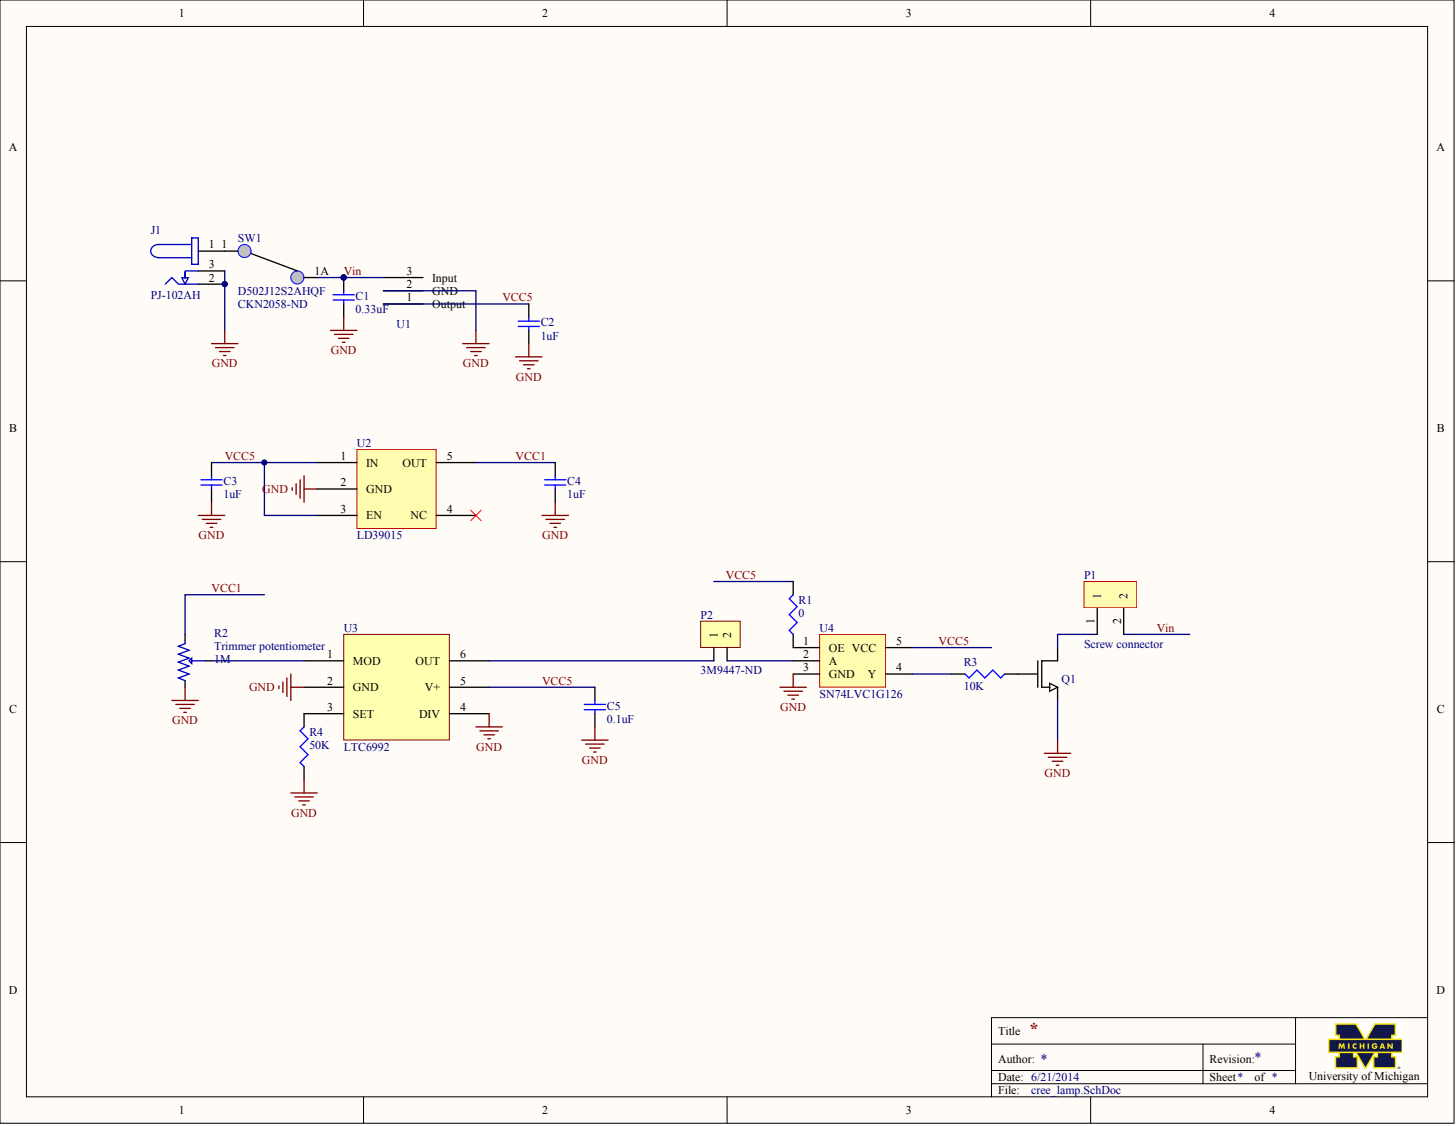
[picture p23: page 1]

* Title | University of Michigan

Author: * | Revision: *
Date: 6/21/2014 | Sheet * of *

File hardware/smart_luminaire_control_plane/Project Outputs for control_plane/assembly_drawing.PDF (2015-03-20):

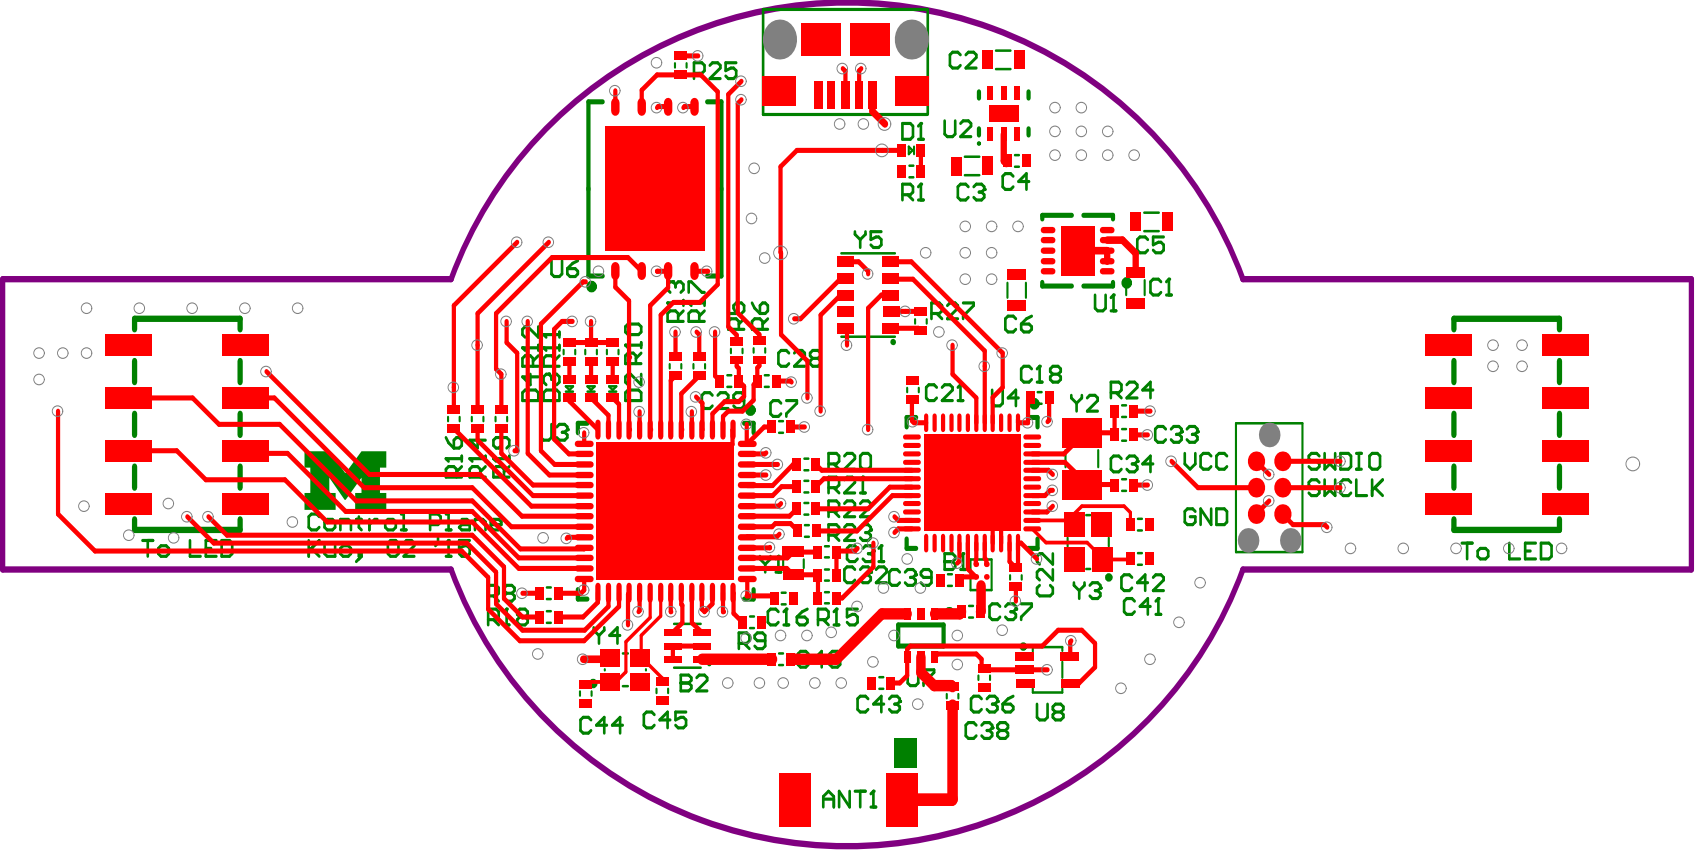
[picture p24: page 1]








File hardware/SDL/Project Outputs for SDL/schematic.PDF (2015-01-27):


JTAG_TDO

BLE_RDY
BLE_ACTIVE

Network_INT

RTC_INT
RTC_CLKOUT

JTAG_TCK

SDL a Main Title | University of Michigan

Author: Ye-Sheng Kuo | Revision:
Date: | Sheet of











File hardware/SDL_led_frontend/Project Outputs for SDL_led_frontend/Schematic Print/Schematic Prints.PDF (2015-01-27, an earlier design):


T i t l e SDL - LED frontend | U n i vers i t y of Mich i gan

A u t h or: Y e-S h e n g Ku o | Rev i s i o n : 1
Date: 8 / 2 8 / 2 0 1 4 | Sheet 1 o f 1


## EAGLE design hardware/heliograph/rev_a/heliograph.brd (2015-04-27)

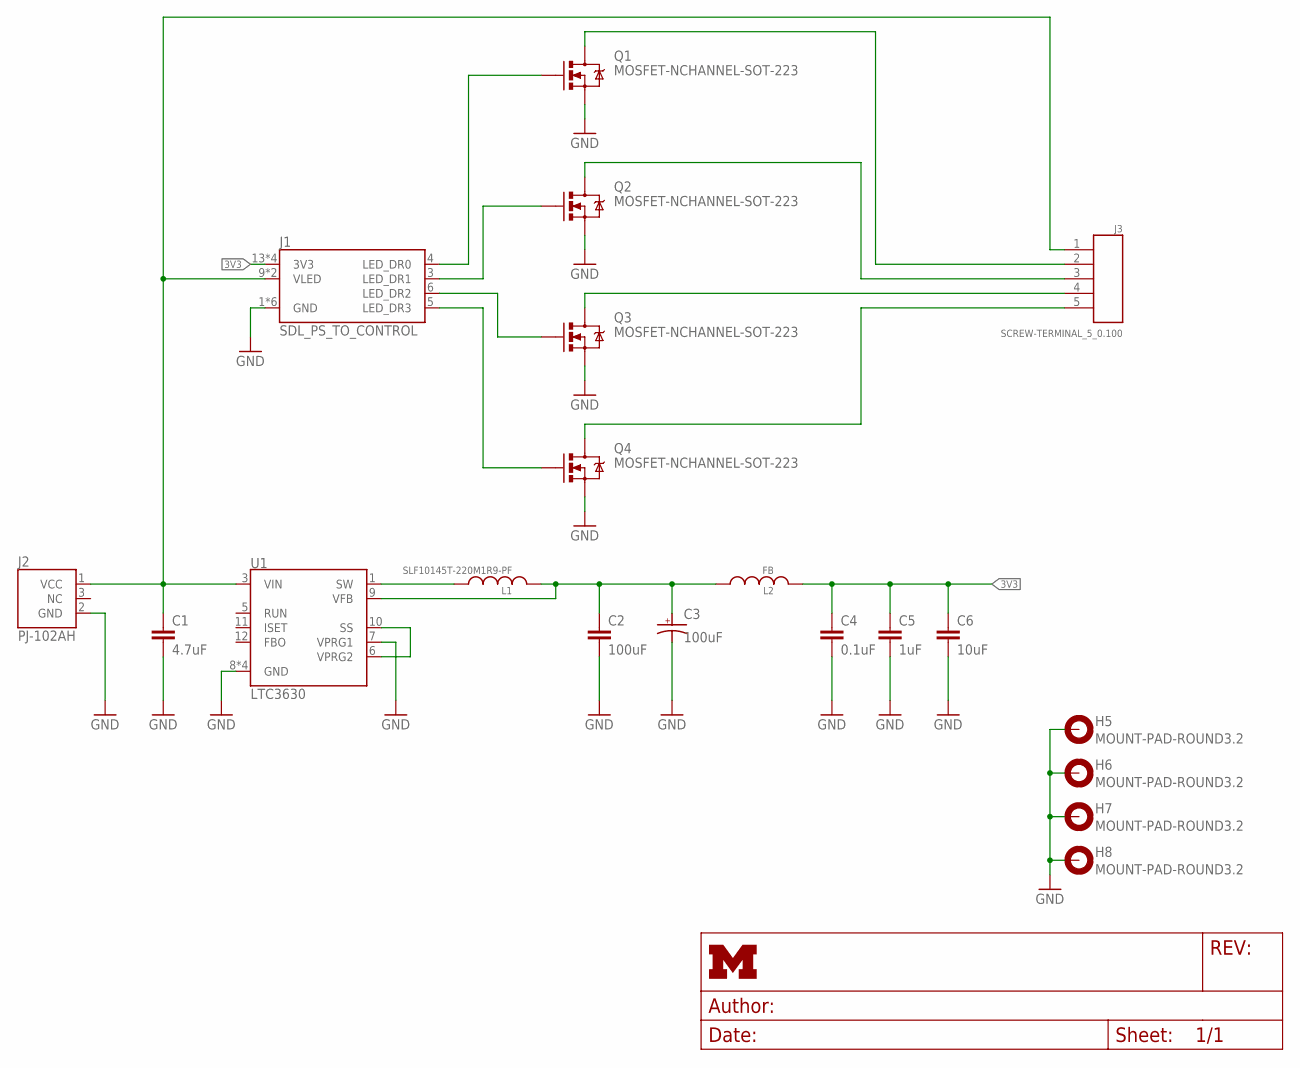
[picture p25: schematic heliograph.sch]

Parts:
C1: 4.7uF; C2220K; DIGIKEY 445-1450-1-ND
C2: 100uF; C1210; DIGIKEY 1276-3364-1-ND
C3: 100uF; 2917-POL; DIGIKEY 399-3769-1-ND
C4: 0.1uF; C0603; DIGIKEY 445-1316-1-ND
C5: 1uF; C0603; DIGIKEY 445-1604-1-ND
C6: 10uF; C0603; DIGIKEY 445-9065-1-ND
H5, H6, H7, H8: MOUNT-PAD-ROUND3.2; 3,2-PAD
J1: SDL_PS_TO_CONTROL
J2: PJ-102AH
J3: SCREW-TERMINAL_5_0.100; CONN_BLOCK_5
L1: SLF10145T-220M1R9-PF; SLF10145
L2: FB; 0603_CAP; DIGIKEY 490-1011-1-ND
Q1, Q2, Q3, Q4: MOSFET-NCHANNEL-SOT-223; SOT-223; DIGIKEY 568-9714-1-ND
U1: LTC3630; MSOP-16(12)

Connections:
3V3: C4.1, C5.1, C6.1, J1.13 (3V3), J1.14 (3V3), J1.15 (3V3), J1.16 (3V3), L2.2
GND: C1.2, C2.2, C3.- (ANODE), C4.2, C5.2, C6.2, H5.B3,2, H6.B3,2, H7.B3,2, H8.B3,2, J1.1 (GND), J1.2 (GND), J1.7 (GND), J1.8 (GND), J1.11 (GND), J1.12 (GND), J2.2 (GND), Q1.3 (S), Q2.3 (S), Q3.3 (S), Q4.3 (S), U1.7 (VPRG1), U1.8 (GND), U1.14 (GND), U1.16 (GND), U1.17 (GND)
unnamed: L1.1, U1.1 (SW)
unnamed: C2.1, C3.+ (CATHODE), L1.2, L2.1, U1.9 (VFB)
unnamed: U1.6 (VPRG2), U1.10 (SS)
unnamed: J1.4 (LED_DR0), Q1.1 (G)
unnamed: J1.3 (LED_DR1), Q2.1 (G)
unnamed: J1.6 (LED_DR2), Q3.1 (G)
unnamed: J1.5 (LED_DR3), Q4.1 (G)
unnamed: J3.3, Q2.2 (D), Q2.4 (D)
unnamed: J3.2, Q1.2 (D), Q1.4 (D)
unnamed: J3.5, Q4.2 (D), Q4.4 (D)
unnamed: J3.4, Q3.2 (D), Q3.4 (D)
VIN: C1.1, J1.9 (VLED), J1.10 (VLED), J2.1 (VCC), J3.1, U1.3 (VIN)

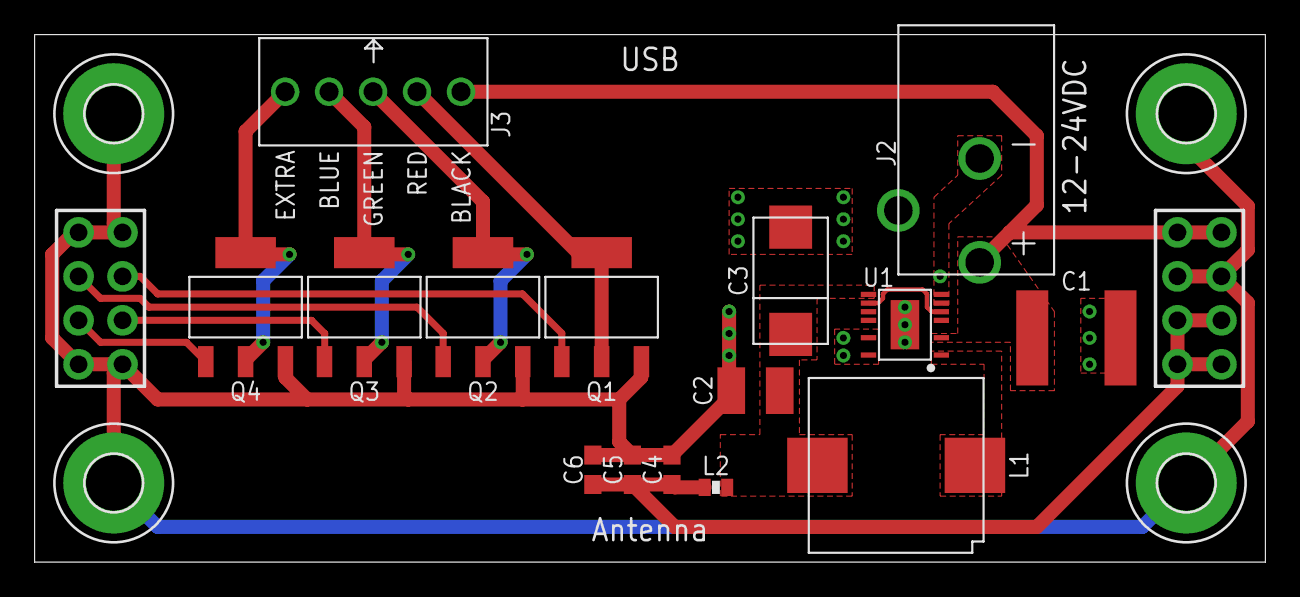
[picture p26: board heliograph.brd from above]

Board: 2 copper layers, 71.1 x 30.5 mm, 20 parts (0 on the bottom side), 14 nets.

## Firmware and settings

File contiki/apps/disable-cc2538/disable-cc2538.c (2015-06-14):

/*
 * Minimal cc2538 code
 *
 * Blinks an LED on the Atum board (https://github.com/lab11/atum) or SDL board
 *  (https://github.com/lab11/torch). Expects a UART bootloader to already be
 *  programmed onto the cc2538
 *
 * Branden Ghena (brghena@umich.edu) - 2015
 */

/* No includes necessary */

/* GPIO pin definitions */
#define GPIO_A_BASE  0x400D9000  // GPIO A base address
#define GPIO_B_BASE  0x400DA000  // GPIO B base address
#define GPIO_C_BASE  0x400DB000  // GPIO C base address
#define GPIO_D_BASE  0x400DC000  // GPIO D base address
#define GPIO_DIR     0x00000400  // Direction offset
#define GPIO_DATA    0x00000000  // Data offset

#define RFSWITCH_NUM  5

/* Pin definitions for various cc2538 systems */
#define ATUM_LEDS_BASE GPIO_D_BASE
#define ATUM_RED_LED   3
#define ATUM_BLUE_LED  4
#define ATUM_GREEN_LED 5

#define SDL_LEDS_BASE  GPIO_C_BASE
#define SDL_RED_LED    1
#define SDL_GREEN_LED  0
#define SDL_BIG_LED    5

#define assert_wfi() do { asm("wfi"::); } while(0)

/* Function prototypes */
void reset_handler(void);
int main(void);

/* Pointers to stack and sections */
static unsigned int stack[512]; // Allocate stack space
extern unsigned long _text;  // Linker construct indicating .text section location
extern unsigned long _etext;
extern unsigned long _data;
extern unsigned long _edata;
extern unsigned long _bss;
extern unsigned long _ebss;

/* Boot loader backdoor
 *
 * This is important for loading code through UART (via USB) instead of JTAG.
 * With a JTAG loader, this entire section is unncessary.
 */
#define FLASH_CCA_BOOTLDR_CFG_ENABLE 0xF0FFFFFF        // Enable backdoor function
#define FLASH_CCA_BOOTLDR_CFG_PORT_A_PIN_S 24          // Selected pin on pad A shift ??
#define FLASH_CCA_CONF_BOOTLDR_BACKDOOR_PORT_A_PIN 2   // Pin PA_2 activates the boot loader
#define FLASH_CCA_CONF_BOOTLDR_BACKDOOR_ACTIVE_HIGH 0  // A logic low level activates the boot loader
#define FLASH_CCA_BOOTLDR_CFG_ACTIVE_LEVEL 0
#define FLASH_CCA_IMAGE_VALID 0x00000000               // Indicates valid image in flash
#define FLASH_CCA_BOOTLDR_CFG ( FLASH_CCA_BOOTLDR_CFG_ENABLE \
        | FLASH_CCA_BOOTLDR_CFG_ACTIVE_LEVEL \
        | (FLASH_CCA_CONF_BOOTLDR_BACKDOOR_PORT_A_PIN << FLASH_CCA_BOOTLDR_CFG_PORT_A_PIN_S) )

typedef struct{
    unsigned int bootldr_cfg;
    unsigned int image_valid;
    const void *app_entry_point;
    unsigned char lock[32];
} flash_cca_lock_page_t;

__attribute__ ((section(".flashcca"), used))
const flash_cca_lock_page_t __cca = {
    FLASH_CCA_BOOTLDR_CFG,         // Boot loader backdoor configuration
    FLASH_CCA_IMAGE_VALID,         // Image valid
    &_text,                        // Vector table located at the start of .text
    {   0xFF, 0xFF, 0xFF, 0xFF, 0xFF, 0xFF, 0xFF, 0xFF,
        0xFF, 0xFF, 0xFF, 0xFF, 0xFF, 0xFF, 0xFF, 0xFF,
        0xFF, 0xFF, 0xFF, 0xFF, 0xFF, 0xFF, 0xFF, 0xFF,
        0xFF, 0xFF, 0xFF, 0xFF, 0xFF, 0xFF, 0xFF, 0xFF } // Unlock all pages and debug
};

/* Vector table */
__attribute__ ((section(".vectors"), used))
void(*const vectors[])(void) = {
    (void (*)(void))((unsigned int)stack + sizeof(stack)),   /* Stack pointer */
    reset_handler,    /* Reset handler */
    0,                /* The NMI handler */
    0,                /* The hard fault handler */
    0,                /* 4 The MPU fault handler */
    0,                /* 5 The bus fault handler */
    0,                /* 6 The usage fault handler */
    0,                /* 7 Reserved */
    0,                /* 8 Reserved */
    0,                /* 9 Reserved */
    0,                /* 10 Reserved */
    0,                /* 11 SVCall handler */
    0,                /* 12 Debug monitor handler */
};

/* Reset handler
 *
 * This handler is run on reset of the microcontroller, i.e. it is the code
 *  that runs when the microcontroller starts. It needs to copy over
 *  initialization data for global variables and then enter the user code
 */
void reset_handler(void) {

    // Copy the data segment intializers from Flash to SRAM
    unsigned long* data_src = &_etext;
    unsigned long* data_dst;
    for (data_dst = &_data; data_dst < &_edata;) {
        *data_dst++ = *data_src++;
    }

    // Zero-fill the bss segment
    __asm("    ldr     r0, =_bss         \n"
          "    ldr     r1, =_ebss        \n"
          "    mov     r2, #0            \n"
          "    .thumb_func               \n"
          "zero_loop:                    \n"
          "        cmp     r0, r1        \n"
          "        it      lt            \n"
          "        strlt   r2, [r0], #4  \n"
          "        blt     zero_loop     \n"
          );

    // Call user code
    main();

    // End here if code returns
    while (1);
}

/* Main code
 *
 * This is the user's application
 */
int main(void) {

	// Sets the LED pin to be an output
    *((volatile unsigned int*)(GPIO_B_BASE | GPIO_DIR)) |= (1 << RFSWITCH_NUM);

    // switch antenna to nRF51822
    *((volatile unsigned int*)(((GPIO_B_BASE) | GPIO_DATA) + ((1 << RFSWITCH_NUM) << 2))) = 0x00;

    assert_wfi();

    return 0;
}

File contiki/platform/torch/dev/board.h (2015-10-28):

/*
 * Copyright (c) 2012, Texas Instruments Incorporated - http://www.ti.com/
 * All rights reserved.
 *
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
 * 3. Neither the name of the copyright holder nor the names of its
 *    contributors may be used to endorse or promote products derived
 *    from this software without specific prior written permission.
 *
 * THIS SOFTWARE IS PROVIDED BY THE COPYRIGHT HOLDERS AND CONTRIBUTORS
 * ``AS IS'' AND ANY EXPRESS OR IMPLIED WARRANTIES, INCLUDING, BUT NOT
 * LIMITED TO, THE IMPLIED WARRANTIES OF MERCHANTABILITY AND FITNESS
 * FOR A PARTICULAR PURPOSE ARE DISCLAIMED.  IN NO EVENT SHALL THE
 * COPYRIGHT HOLDER OR CONTRIBUTORS BE LIABLE FOR ANY DIRECT, INDIRECT,
 * INCIDENTAL, SPECIAL, EXEMPLARY, OR CONSEQUENTIAL DAMAGES
 * (INCLUDING, BUT NOT LIMITED TO, PROCUREMENT OF SUBSTITUTE GOODS OR
 * SERVICES; LOSS OF USE, DATA, OR PROFITS; OR BUSINESS INTERRUPTION)
 * HOWEVER CAUSED AND ON ANY THEORY OF LIABILITY, WHETHER IN CONTRACT,
 * STRICT LIABILITY, OR TORT (INCLUDING NEGLIGENCE OR OTHERWISE)
 * ARISING IN ANY WAY OUT OF THE USE OF THIS SOFTWARE, EVEN IF ADVISED
 * OF THE POSSIBILITY OF SUCH DAMAGE.
 */
/** \addtogroup cc2538
 * @{
 *
 * \defgroup cc2538-smartrf SmartRF06EB Peripherals
 *
 * Defines related to the SmartRF06EB
 *
 * This file provides connectivity information on LEDs, Buttons, UART and
 * other SmartRF peripherals
 *
 * Notably, PC0 is used to drive LED1 as well as the USB D+ pullup. Therefore
 * when USB is enabled, LED1 can not be driven by firmware.
 *
 * This file can be used as the basis to configure other platforms using the
 * cc2538 SoC.
 * @{
 *
 * \file
 * Header file with definitions related to the I/O connections on the TI
 * SmartRF06EB
 *
 * \note   Do not include this file directly. It gets included by contiki-conf
 *         after all relevant directives have been set.
 */
#ifndef BOARD_H_
#define BOARD_H_

#include "dev/gpio.h"
#include "dev/nvic.h"
/*---------------------------------------------------------------------------*/
/** \name SmartRF LED configuration
 *
 * LEDs on the SmartRF06 (EB and BB) are connected as follows:
 * - LED1 (Red)    -> PC0
 * - LED2 (Yellow) -> PC1
 * - LED3 (Green)  -> PC2
 * - LED4 (Orange) -> PC3
 *
 * LED1 shares the same pin with the USB pullup
 * @{
 */
/*---------------------------------------------------------------------------*/
/* Some files include leds.h before us, so we need to get rid of defaults in
 * leds.h before we provide correct definitions */
#undef LEDS_GREEN
#undef LEDS_BLUE
#undef LEDS_RED
#undef LEDS_CONF_ALL

#define LEDS_BLUE                4  /**< PC2 */
#define LEDS_RED                 2  /**< PC1 */
#define LEDS_GREEN               1  /**< PC0 */
#define LEDS_CONF_ALL            7

/* Notify various examples that we have LEDs */
#define PLATFORM_HAS_LEDS        1

#define LED_BLUE_BASE            GPIO_C_BASE
#define LED_RED_BASE             GPIO_C_BASE
#define LED_GREEN_BASE           GPIO_C_BASE
#define LED_BLUE_MASK            GPIO_PIN_MASK(2)
#define LED_RED_MASK             GPIO_PIN_MASK(1)
#define LED_GREEN_MASK           GPIO_PIN_MASK(0)


// #define LEDS_BLUE                4  /**< PC2 */
// #define LEDS_RED                 2  /**< PC1 */
// #define LEDS_GREEN               1  /**< PC0 */
// #define LEDS_CONF_ALL            7

// /* Notify various examples that we have LEDs */
// #define PLATFORM_HAS_LEDS        1

// #define LED_BLUE_BASE            GPIO_C_BASE
// #define LED_RED_BASE             GPIO_C_BASE
// #define LED_GREEN_BASE           GPIO_C_BASE
// #define LED_BLUE_MASK            GPIO_PIN_MASK(2)
// #define LED_RED_MASK             GPIO_PIN_MASK(1)
// #define LED_GREEN_MASK           GPIO_PIN_MASK(0)
/** @} */
/*---------------------------------------------------------------------------*/
/** \name nRF51822 BLE
 *
 */
#define NRF51822_INT_PORT_NUM  GPIO_B_NUM
#define NRF51822_INT_PIN       4
#define NRF51822_INT_BASE      GPIO_PORT_TO_BASE(NRF51822_INT_PORT_NUM)
#define NRF51822_INT_MASK      GPIO_PIN_MASK(NRF51822_INT_PIN)
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

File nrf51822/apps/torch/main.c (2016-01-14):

/*

Bluetooth low energy Co-Processor

This app makes the nRF51822 into a BLE SPI slave peripheral.

See bcp.h for the list of valid commands the SPI master can issue.

*/

#include <stdint.h>
#include <stdio.h>
#include <string.h>
#include "nordic_common.h"
#include "nrf.h"
#include "nrf_sdm.h"
#include "ble.h"
#include "ble_db_discovery.h"
#include "softdevice_handler.h"
#include "app_util.h"
#include "app_error.h"
#include "ble_advdata_parser.h"
#include "ble_conn_params.h"
#include "ble_hci.h"
#include "boards.h"
#include "nrf_gpio.h"
#include "pstorage.h"
// #include "device_manager.h"
#include "app_trace.h"
#include "ble_hrs_c.h"
#include "ble_bas_c.h"
#include "app_util.h"
#include "app_timer.h"

#include "simple_ble.h"
#include "eddystone.h"

#include "led.h"
#include "boards.h"

#include "bcp_spi_slave.h"
#include "ble_config.h"
#include "bcp.h"
#include "interrupt_event_queue.h"

#define PHYSWEB_URL "goo.gl/449K5X"

bool bcp_irq_advertisements = false;


#define TORCH_SHORT_UUID               0x65b8 // service UUID
#define TORCH_CHAR_LED_SHORT_UUID      0x65b9 // control the LEDs on CC2538
#define TORCH_CHAR_WHITELED_SHORT_UUID 0x65ba // control the LEDs on CC2538

// service and characteristic handles
simple_ble_service_t service_handle = {
    .uuid128 = {{0xef, 0x1d, 0x66, 0x4d, 0x06, 0xa5, 0x4f, 0x0a,
                 0x93, 0x31, 0x23, 0x8c, 0x65, 0xb8, 0x7e, 0xb9}}
};
simple_ble_char_t char_led_handles = {.uuid16 = TORCH_CHAR_LED_SHORT_UUID};
simple_ble_char_t char_whiteled_handles = {.uuid16 = TORCH_CHAR_WHITELED_SHORT_UUID};


// State for this application
static ble_app_t app;
simple_ble_app_t* simple_ble_app;


// Intervals for advertising and connections
static simple_ble_config_t ble_config = {
    .platform_id       = 0x50,              // used as 4th octect in device BLE address
    .device_id         = DEVICE_ID_DEFAULT,
    .adv_name          = DEVICE_NAME,       // used in advertisements if there is room
    .adv_interval      = MSEC_TO_UNITS(1000, UNIT_0_625_MS),
    .min_conn_interval = MSEC_TO_UNITS(8, UNIT_1_25_MS),
    .max_conn_interval = MSEC_TO_UNITS(10, UNIT_1_25_MS),
};





// Send all received advertisements to the host
void bcp_sniff_advertisements () {
    led_off(LED_0);
    bcp_irq_advertisements = true;
}

// Update the nRF's characteristic based on the setting of the CC2538 leds.
void main_set_led_state (uint8_t leds_state) {
    app.led_state = leds_state;
}



void bcp_interrupt_host () {
    nrf_gpio_pin_set(INTERRUPT_PIN);
}

void bcp_interupt_host_clear () {
    nrf_gpio_pin_clear(INTERRUPT_PIN);
}



// Function for handling the WRITE CHARACTERISTIC BLE event.
void ble_evt_write (ble_evt_t* p_ble_evt) {
    ble_gatts_evt_write_t* p_evt_write = &p_ble_evt->evt.gatts_evt.params.write;

    if (simple_ble_is_char_event(p_ble_evt, &char_led_handles)) {
        app.led_state = p_evt_write->data[0];

        // Notify the CC2538 that the LED characteristic was written to
        interrupt_event_queue_add(BCP_RSP_LED, 1, p_evt_write->data);

    } else if (simple_ble_is_char_event(p_ble_evt, &char_whiteled_handles)) {
        app.whiteled_dutycycle = p_evt_write->data[0];

        // Notify the CC2538 that the LED characteristic was written to
        interrupt_event_queue_add(BCP_RSP_WHITE_LIGHT, 1, p_evt_write->data);

    }
}



/*******************************************************************************
 *   INIT FUNCTIONS
 ******************************************************************************/


void services_init (void) {

    simple_ble_add_service(&service_handle);

    //add the characteristic that exposes a blob of interrupt response
    simple_ble_add_characteristic(1, 1, 0, 0,  // read, write, notify, vlen
                                  1, &app.led_state,
                                  &service_handle,
                                  &char_led_handles);

    //add the characteristic that exposes a blob of interrupt response
    simple_ble_add_characteristic(1, 1, 0, 0,  // read, write, notify, vlen
                                  1, &app.whiteled_dutycycle,
                                  &service_handle,
                                  &char_whiteled_handles);
}

void initialize_app_timers (void) {
    APP_TIMER_INIT(APP_TIMER_PRESCALER, APP_TIMER_MAX_TIMERS, APP_TIMER_OP_QUEUE_SIZE, false);
}

int main(void) {
    //
    // Initialization
    //

    // Setup the particular platform
    platform_init();

    // Setup BLE and services
    simple_ble_app = simple_ble_init(&ble_config);
    //simple_adv_service(&torch_uuid);

    // Setup the advertisement to use the Eddystone format.
    // We include the device name in the scan response
    ble_advdata_t srdata;
    memset(&srdata, 0, sizeof(srdata));
    srdata.name_type = BLE_ADVDATA_FULL_NAME;
    eddystone_adv(PHYSWEB_URL, &srdata);

    // Make this a SPI slave to the CC2538
    spi_slave_example_init();


    while (1) {
        power_manage();
    }
}

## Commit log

2015-01-27 SDL altium files
    [Bill of Materials-SDL.xlsx, Bill of Materials-led_frontend.xlsx, SDL.PrjPcb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]
2015-03-15 Altium files for 2nd version of led frontend
    [Bill of Materials-led_frontend.xlsx, PCB1.PcbDoc, connectors.~(1).PcbLib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]
2015-03-17 added solidworks models
    start of frame, bulb holder
    [frame.SLDPRT, globe_mount.SLDPRT, globe_mount.STL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]
2015-03-17 version 3 of globe mount
    [globe_mount.SLDPRT, globe_mount3.STL]
2015-03-17 added frame assembly
    [frame.SLDASM, frame_12.SLDPRT, frame_13.SLDPRT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]
2015-03-20 control plane for sdl
    [Bill of Materials-control_plane.xlsx, RF.~(1).PcbLib, RF.~(2).SchLib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]
2015-03-20 working on pwm
2015-03-20 pwm test
2015-03-21 Active High DTR pin. Fixes bootloader problem
    Requires update to cc2538-bsl script in Contiki
    [contiki-conf.h]
2015-03-29 First pass at phone holder
    Add a holder for the lumia 1020 to mount on the OptiTrack calibration
    tool.
    [OptiTrack_Calibrator.ipt, Phone_Holder.ipt, Phone_Holder.stl]
2015-03-30 Gen 2 phone holder
    A little more tolerance in phone holder; top thumb hole; clip corner
    [Phone_Holder.ipt, Phone_Holder.stl]
2015-03-30 Laser Range Holder for Calibration
    First pass
    [Laser_Holder.ipt, Laser_Holder.stl]
2015-04-04 Revise second hole size for OptiTrack
    Also increase tolerance on phone holder and thickness (stiffness) of
    phone holder.
    [Laser_Holder.ipt, Laser_Holder.stl, OptiTrack_Calibrator.ipt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]
2015-04-04 Tighten phone tol, loosen small hole tolerance
    [Laser_Holder.ipt, Laser_Holder.stl, Phone_Holder.ipt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]
2015-04-05 added extra sdl control boards
2015-04-07 Final Versions of Calibration Prints
    Thicker bases with holes. Fixes two screw sizes in OptiTrack holder.
    [Laser_Holder.ipt, Laser_Holder.stl, Phone_Holder.ipt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]
2015-04-12 frame parts
    [frame_12.SLDPRT, globe_mount_bulb4.SLDPRT, globe_mount_bulb4.STL]
2015-04-25 added torch mount
    [torch-holder.SLDPRT, torch-holder.STL]
2015-04-27 add heliograph board
    for RGB panels
    [heliograph.brd, heliograph.sch]
2015-04-27 add outline of flare
    [flare.brd, flare.sch]
2015-04-28 wall mount for globe
    [wall_mount.SLDPRT, wall_mount.STL]
2015-06-01 Lights can correctly stay off on reboot
    [coap.c]
2015-06-14 app that puts cc2538 in sleep and antenna -> ble
2015-10-28 updated nrf app to support main led control
